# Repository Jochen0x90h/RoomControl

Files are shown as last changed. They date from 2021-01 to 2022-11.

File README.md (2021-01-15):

RoomControl
===========
Smart home room controller based on nRF52840 with MQTT and and IEEE 802.15.4 radio support. 
Buttons and relays for lights and blinds can also be connected with a local bus using 
LIN physical layer.

Control
-------
This is a 3D printed box with a display and digital potentiometer that gets installed in each
room instead of the floor heating thermostat. It can control the heating valve using an opto-triac,
connect to light and blind switches and relays using LIN physical layer and to battery-free switches
(EnOcan) using an IEEE 802.15.4 radio interface.

Switch
------
This is a wall switch and actor for lights and blinds that can be mounted behind Eltako E-Design
frames and rockers. It connects to the Control via a bus based on LIN physical layer.

Gateway
-------
This is a hat for rpi or compatible single board computers that connects to multiple Controls
via a IEEE 802.15.4 radio network and to an MQTT broker such as mosquitto.

License
-------
This work is licensed under a
[Creative Commons Attribution-NonCommercial-ShareAlike 4.0 International License][cc-by-nc-sa].

[][cc-by-nc-sa]

[cc-by-nc-sa]: http://creativecommons.org/licenses/by-nc-sa/4.0/
[cc-by-nc-sa-image]: https://licensebuttons.net/l/by-nc-sa/4.0/88x31.png

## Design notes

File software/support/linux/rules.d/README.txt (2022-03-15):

These files grant access to usb devices. Copy them into the rules.d directory:

sudo cp 49-nordic-dfu.rules /etc/udev/rules.d/
sudo cp 49-roomcontrol.rules /etc/udev/rules.d/

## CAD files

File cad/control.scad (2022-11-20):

// export checkist
// - resolution of circles high enough? ($fn = 128)
// - drill positions up to date? (gerber/drill2cad.py)
$fn = 128;

// variables

// pcb
pcbWidth = 70;
pcbHeight = 76;
pcbX = 0; // center of pcb
pcbY = 0;
pcbZ1 = 3;
pcbZ2 = pcbZ1+1.6; // mounting surface
pcbX1 = pcbX-pcbWidth/2;
pcbX2 = pcbX+pcbWidth/2;
pcbY1 = pcbY-pcbHeight/2;
pcbY2 = pcbY+pcbHeight/2;

// poti (Bourns PEC12R-4215F-S0024)
potiX = 22;
potiY = -22;
potiH1 = 7; // height of body above pcb (variant with switch)
potiH2 = 11.2; // height of shaft bearing above pcb
potiL = 17.5; // height of shaft end above pcb
potiF = 5; // shaft cutaway
potiZ1 = pcbZ2 + potiH1;
potiZ2 = pcbZ2 + potiH2;
potiZ4 = pcbZ2 + potiL;
potiZ3 = potiZ4 - potiF;
potiD1 = 7; // shaft bearing diameter
potiD2 = 6; // shaft diameter

// base
baseZ1 = 0;
baseZ2 = pcbZ1;

// cover
coverZ1 = pcbZ2;
coverZ2 = potiZ4 + 1; // use height of poti mounted on pcb plus cap
coverFit = 0.4;
coverOverlap = 2.5;

// wheel
wheelD1 = 10; // diameter of shaft
wheelD2 = 39; // diameter of wheel
wheelGap = 0.5; // visible air gab between box and wheel
wheelZ1 = potiZ3;
wheelZ2 = coverZ2 - 3; // thickness of wheel
wheelZ3 = coverZ2;

// pir lens
lensX = -23;
lensY = -30;
lensD1 = 8.9 + 0.1; // tolerance
lensD2 = 10.2 + 0.2; // tolerance
lensZ2 = coverZ2;
lensZ1 = lensZ2 - 4.35;
lensZ0 = lensZ1 - 4.5 - 0.1; // tolerance

// photo diode
photoX = lensX;
photoY = -14;
photoD = 5.1 + 0.1; // tolerance
photoZ2 = coverZ2;
photoZ1 = photoZ2 - 3.85;

// rectangular speaker
//speakerX = 0;
//speakerY = -25;
//speakerWidth = 25 + 0.2; // tolerance
//speakerHeight = 14 + 0.2; // tolerance
//speakerZ2 = wheelZ2 - 2;
//speakerZ1 = speakerZ2 - 4.5; // thickness of speaker

// round speaker
speakerX = 0;
speakerY = -25;
speakerDiameter = 28;
speakerZ2 = wheelZ2 - 2;
speakerZ1 = speakerZ2 - 5.2; // thickness of speaker


// micro usb connector
usbX = 22;
usbWidth = 8;
usbZ2 = pcbZ2 + 3; // thickness of usb connector
usbPlugWidth = 12;
usbPlugThickness = 8; // thickness of plug of usb cable

// ebyte e73 module
e73X = -13;
e73Width = 18.5;
e73Z2 = pcbZ2 + 2;

// display (2.42 inch)
displayTolerance = 0.4;
displayCableWidth1 = 13;
displayCableWidth2 = 16; // where the flat cable is connected to display
displayCableLength = 35;

// display screen (active area of display)
screenX = 0;
screenY = 20.5;
screenWidth = 57.01;
screenHeight = 29.49;
screenOffset = 1.08 + displayTolerance; // distance between upper panel border and upper screen border (tolerance at upper border)
screenX1 = screenX - screenWidth/2;
screenX2 = screenX + screenWidth/2;
screenY1 = screenY - screenHeight/2;
screenY2 = screenY + screenHeight/2;

// display panel
panelWidth = 60.5 + displayTolerance;
panelHeight = 37 + displayTolerance;
panelThickness1 = 1.2; // at side where cable is connected
panelThickness2 = 2.3;
panelX = screenX;
panelX1 = panelX - panelWidth / 2; // left border of panel
panelX2 = panelX + panelWidth / 2; // right border of panel
panelY2 = screenY + screenHeight/2+screenOffset; // upper border of panel
panelY1 = panelY2-panelHeight; // lower border of panel
panelY = (panelY2+panelY1)/2;
panelZ1 = coverZ2 - 1 - panelThickness2;
panelZ2 = coverZ2 - 1 - panelThickness1;
panelZ3 = coverZ2 - 1;
//echo(100+panelX1);
//echo(100-panelY1);
//echo(100+panelX2);
//echo(100-panelY2);

// power supply (34x20x15 https://www.hlktech.com/en/Goods-12.html)
powerX1 = 15.4;
powerX2 = 35.6;
powerY1 = 3.7;
powerY2 = 37.9;
powerZ2 = pcbZ2 + 15 + 0.2; // tolerance
assert(powerZ2 <= panelZ1, "power supply intersects display");

// cable clamps
clampsX1 = -16.3;
clampsX2 = 16.3;
clampsY1 = -10.5;
clampsY2 = 19;
clampsHeight = 13 + 1;


// cable hole
cableX1 = -17.0;
cableY1 = -1.6;
cableX2 = 34;
cableY2 = 10.2;
cableY = (cableY1 + cableY2) / 2;
fixationHeight = cableY2 - cableY1 - 2 * 2;


// box with center/size in x/y plane and z ranging from z1 to z2
module box(x, y, w, h, z1, z2) {
	translate([x-w/2, y-h/2, z1])
		cube([w, h, z2-z1]);
}

module cuboid(x1, y1, x2, y2, z1, z2) {
	translate([x1, y1, z1])
		cube([x2-x1, y2-y1, z2-z1]);
}

module barrel(x, y, d, z1, z2) {
	translate([x, y, z1])
		cylinder(r=d/2, h=z2-z1);
}

module cone(x, y, d1, d2, z1, z2) {
	translate([x, y, z1])
		cylinder(r1=d1/2, r2=d2/2, h=z2-z1);
}

module frustum(x, y, w1, h1, w2, h2, z1, z2) {
	// https://en.wikibooks.org/wiki/OpenSCAD_User_Manual/Primitive_Solids#polyhedron	
	points = [
		// lower square
		[x-w1/2,  y-h1/2, z1],  // 0
		[x+w1/2,  y-h1/2, z1],  // 1
		[x+w1/2,  y+h1/2, z1],  // 2
		[x-w1/2,  y+h1/2, z1],  // 3
		// upper square
		[x-w2/2,  y-h2/2, z2],  // 4
		[x+w2/2,  y-h2/2, z2],  // 5
		[x+w2/2,  y+h2/2, z2],  // 6
		[x-w2/2,  y+h2/2, z2]]; // 7
	faces = [
		[0,1,2,3],  // bottom
		[4,5,1,0],  // front
		[7,6,5,4],  // top
		[5,6,2,1],  // right
		[6,7,3,2],  // back
		[7,4,0,3]]; // left  
	polyhedron(points, faces);
}


// reference parts
// ---------------

module usb() {
	color([0.5, 0.5, 0.5])
	box(x=usbX, y=pcbY1+1, w=usbWidth, h=10, z1=pcbZ2-0.1, z2=usbZ2);		
}

module usbPlug() {
	usbPlugZ1 = (usbZ1+usbZ2)/2-usbPlugThickness/2;
	color([0, 0, 0])
	box(x=usbX, y=pcbY1-10, w=usbPlugWidth, h=14,
		z1=usbPlugZ1, z2=usbPlugZ1+usbPlugThickness);		
}

// ebyte e73 module
module e73() {
	color([0.0, 0.6, 0.0])
	box(x=e73X, y=pcbY1+1, w=e73Width, h=10, z1=pcbZ2-0.1, z2=e73Z2);			
}

// printed circuit board
module pcb() {
	color([0, 0.6, 0, 0.3])
	box(x=pcbX, y=pcbY, w=pcbWidth, h=pcbHeight,
		z1=pcbZ1, z2=pcbZ2);
}

// digital potentiometer
module poti() {
	x = potiX;
	y = potiY;
	color([0.5, 0.5, 0.5]) {
		box(x, y, 13.4, 12.4, pcbZ2, potiZ1);
		box(x, y, 15, 6, pcbZ2, potiZ1);
		barrel(x, y, potiD1, pcbZ2, potiZ2);
		difference() {
			barrel(x, y, potiD2, pcbZ2, potiZ4);
			box(x, y+potiD2/2, 10, 3, potiZ3, potiZ4+0.5);
		}
	}
}

//module relays() {
//	color([1, 1, 1]) {
//		cuboid(-23.2, 22.8, 37.5, 37.5, pcbZ2, pcbZ2+9.2);
//	}
//}

// transformer for power supply
module power() {
	color([0, 0, 0]) {
		cuboid(powerX1, powerY1, powerX2, powerY2, pcbZ2-0.1, powerZ2);
	}	
}

// cable clamps
module clamps() {
	color([0.8, 0.8, 0.8]) {
		cuboid(clampsX1, clampsY1, clampsX2, clampsY2,
			pcbZ1 - clampsHeight, pcbZ1);
	}		
}


// 

module wheel() {
	x = potiX;
	y = potiY;

	// wheel
	difference() {
		// wheel
		barrel(x, y, wheelD2, wheelZ2, wheelZ3);

		// cutout for poti shaft (with tolerance)
		box(x=x, y=y, w=10, h=4.5, z1=1, z2=potiZ4+0.1);
		box(x=x, y=y, w=4.5, h=10, z1=1, z2=potiZ4+0.1);
	}
	
	// shaft holder for poti shaft
	difference() {
		intersection() {
			// box that has 1mm wall on sides
			box(x=x, y=y, w=8, h=8, z1=wheelZ1, z2=wheelZ2+1);

			// make round corners
			barrel(x, y, wheelD1, wheelZ1, wheelZ2+1);
		}

		// subtract rounded hole
		intersection() {
			box(x=x, y=y, w=potiD2, h=potiD2, z1=wheelZ1-1, z2=wheelZ3-1);
			barrel(x, y, 3.8*2, wheelZ1-1, wheelZ3-1);
		}
	}
	
	// poti shaft cutaway
	difference() {
		// fill shaft cutaway which is 1.5mm
		union() {
			box(x=x, y=y+2.5, w=1, h=2, z1=potiZ3, z2=wheelZ3-2);
			box(x=x, y=y+2.0, w=2, h=1, z1=potiZ3, z2=wheelZ3-2);
		}

		// subtract slanted corners to ease insertion of poti shaft
		translate([x, y+1.6, potiZ3-0.5])
			rotate([30, 0, 0])
				box(x=0, y=0, w=4, h=1, z1=0, z2=2);
	}
}

// for adding wheel base
module wheelBase(x, y) {
	// base in z-direction: 1mm air, 2mm wall
	barrel(x, y, wheelD2+(wheelGap+2)*2, wheelZ2-1-2, wheelZ3);
	
	// shaft radial: 5mm wheel shaft, air gap, 1mm wall
	// zhaft z-direction: 2mm wall, 1mm air, wheel
	barrel(x, y, wheelD1+(wheelGap+1)*2, wheelZ1-2-1, wheelZ3);

	// shaft radial: poti shaft, no air gap, 1.5mm wall
	barrel(x, y, potiD1+1.5*2, potiZ1, wheelZ3);
}

// for subtracting from wheel base
module potiCutout(x, y) {
	// cutout for wheel: 3mm wheel, 1mm air
	barrel(x, y, wheelD2+wheelGap*2, wheelZ2-1, coverZ2+1);

	// hole for poti shaft bearing
	barrel(x, y, potiD1+0.1*2, pcbZ2, wheelZ2);

	// hole for poti shaft
	barrel(x, y, potiD2+0.1*2, pcbZ2, wheelZ2);

	// hole for wheel shaft
	barrel(x, y, wheelD1+wheelGap*2, wheelZ1-1, wheelZ2);
}

// snap lock between cover and base
module snap(x, l) {
	translate([x, 0, coverZ1+1])
		rotate([0, 45, 0])
			cuboid(x1=-0.65, x2=0.65, y1=-l/2, y2=l/2, z1=-0.65, z2=0.65);
}

module drill(x, y, d) {
	h1 = d + 1;
	w1 = h1;
	h2 = d + 0.2;
	w2 = h2;
	frustum(x, y, w2, h2, w1, h1, pcbZ1-1.5, pcbZ1+0.1);
	box(x, y, w2, h2, pcbZ2-4, pcbZ1);	
}
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

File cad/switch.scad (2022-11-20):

$fn = 128;

// production constraints
minWall = 1;
minGap = 0.8;

// pcb
pcbZ1 = 0;
pcbZ2 = 1.6;
pinZ = pcbZ1 + 4; // pins soldered into through-hole pads

// dimensions
Z = 12; // overall height in Z-direction
rockerZ = 16; // height of rocker surface

// actuation angle
angle = 5.4; // maximum actuation angle
tanAngle = tan(angle);


// axis
axisD = 2.5;
axisX2 = /*37.2*/36.8 / 2; // outer rocker axis
axisX1 = 37.2/2 - 15.85; // inner rocker axis
axisZ = Z - 1.3;
axisCoutoutWidth = 7;
axisCutoutZ = axisZ - 2.5;

// body
bodyWidth = 40;

// switch actuator
actuatorWidth = 3.2;
actuatorX = 17 / 2;
actuatorY = 20 / 2;
actuatorZ = axisZ - 1.3 + 2;


// micro switch Omron D2F-01
switchWidth = 5.8 + 0.2; // tolerance
switchHeight = 12.8;
switchX = switchHeight / 2;
switchY = actuatorY;
switchZ2 = pcbZ2+6.5;//actuatorZ - 1 - 1;
switchZ1 = switchZ2 - 5;
switchZ0 = switchZ1 - 1.5;
switchZ3 = switchZ2 + 1; // actuator
switchesX2 = switchX + switchHeight / 2;
switchesWidth = switchesX2 * 2;
switchesY2 = switchY + switchWidth / 2;


// mount
mountWidth = 48;
mountHeight = 48;
mountRight = mountWidth / 2;
mountTop = mountHeight / 2;

// mount part 1 (sides)
mount1Width = 4;
mount1Height = 18.2;
mount1X = mountRight - mount1Width / 2;
mount1Y = mount1Height / 2;

// mount part 2 (corners, rotated by 45°)
mount2Width = 9.5;
mount2Height = 2.25;
mount2Y2 = 58.1 / 2;
mount2Y = mount2Y2 - mount2Height / 2;

// mount part 3 (top/bottom)
mount3Width = 18.2 * 2;
mount3Height = 3;//mountTop - barY2 - minGap;
mount3Y = mountTop - mount3Height / 2;

// mount part 4 (spring support)
mount4Width = 5;
mount4Height = mountTop - switchesY2;
mount4Y = (mountTop + switchesY2) / 2;

// mount Z
mountZ1 = pcbZ2;
mountZ2 = mountZ1 + 2; // thickness of frame (Eltako E-Design)


// clamp part 1 (sides)
clamp1Width = 1.5;
clamp1Height = mount1Height;
clamp1X = mountRight - clamp1Width / 2;
clamp1Y = mount1Y;

// clamp part 2 (corners and frame clamps, rotated by 45°)
clamp2Width1 = mount2Width;
clamp2Width2 = 6.5;
clamp2Height = 1.5;
clamp2Y = mount2Y2 - clamp2Height / 2;

// clamp Z
clampZ1 = mountZ2 + minGap;
clampZ2 = Z - mountTop * tanAngle; // fits under rockers at top/bottom edge
clampZ3 = Z - mount1Height * tanAngle;


// middle carrier
carrierWidth = mountWidth;
carrierHeight = (switchY - switchWidth / 2) * 2;
carrierZ1 = pcbZ2;
carrierZ2 = pinZ + 1;

// top above switches
topWidth = switchesWidth;
topHeight = switchWidth + 2;
topY = switchY;
topY1 = switchY - topHeight/2;
topY2 = switchY + topHeight/2;

// screws
screwX = 20.5;
screwY = -4;
screwD = 2.5;
screwMountSize = 6; // diameter of screw mount

// actuator bar (front)
barWidth = (32 + 2) / 2;
barX = barWidth / 2;
barY1 = 34.4 / 2;
barY2 = 40 / 2;
barY = (barY1 + barY2) / 2;
barZ2 = axisZ - 1.3;
barZ1 = barZ2 - 1.5; // thickness of bar
//echo(barZ1);
barHeight = barY2 - barY1;
barTravel = barY2 * tanAngle;
//echo(barTravel);

// spring below actuator bar
springZ = (pcbZ2 + barZ1) / 2; // "middle" of spring
springZ1 = springZ - barTravel / 2; // lower block
springZ2 = springZ + barTravel / 2; // upper block


// led (Kingbright WP710A10LZGCK)
//ledX = 15.75;
//ledY = 23;//22;
ledX = 15.5;
ledY = 0;
ledD1 = 2.9;
ledD2 = 3.2;
ledZ2 = rockerZ - 2.5 - ledY * tanAngle - 0.1; // tolerance
ledZ1 = ledZ2 - 3.6; 
ledZ0 = ledZ2 - 5.4;


// lever arm
leverX1 = switchesX2 + 1; // 1mm left/right tolerance
leverX2 = axisX2 - minWall - minGap;
leverX = (leverX1 + leverX2) / 2;
leverY1 = ledD2 / 2;
leverY2 = topY2 + minGap;
leverY = (leverY1 + leverY2) / 2;
leverWidth = leverX2 - leverX1;
leverHeight = leverY2 - leverY1;

// lever front
front1Y1 = topY2 + minGap;
front1Y2 = barY1 - minGap;
front1Y = (front1Y1 + front1Y2) / 2;
front1Height = front1Y2 - front1Y1;
front2Y1 = topY2 + minGap;
front2Y2 = 33.3 / 2;
front2Y = (front2Y1 + front2Y2) / 2;
front2Height = front2Y2 - front2Y1;

// lever Z
leverZ1 = pinZ + front1Y1 * tanAngle;
leverZ2 = Z - 4;



// box with center/size in x/y plane and z ranging from z1 to z2
module box(x, y, w, h, z1, z2) {
	translate([x-w/2, y-h/2, z1])
		cube([w, h, z2-z1]);
}

module cuboid(x1, y1, x2, y2, z1, z2) {
	translate([x1, y1, z1])
		cube([x2-x1, y2-y1, z2-z1]);
}

module barrel(x, y, d, z1, z2) {
	translate([x, y, z1])
		cylinder(r=d/2, h=z2-z1);
}

module axis(x, y, d, l, z) {
	translate([x-l/2, y, z])
		rotate([0, 90, 0])
			cylinder(r=d/2, h=l);
}

module frustum(x, y, w1, h1, w2, h2, z1, z2) {
	// https://en.wikibooks.org/wiki/OpenSCAD_User_Manual/Primitive_Solids#polyhedron	
	points = [
		// lower square
		[x-w1/2,  y-h1/2, z1],  // 0
		[x+w1/2,  y-h1/2, z1],  // 1
		[x+w1/2,  y+h1/2, z1],  // 2
		[x-w1/2,  y+h1/2, z1],  // 3
		// upper square
		[x-w2/2,  y-h2/2, z2],  // 4
		[x+w2/2,  y-h2/2, z2],  // 5
		[x+w2/2,  y+h2/2, z2],  // 6
		[x-w2/2,  y+h2/2, z2]]; // 7
	faces = [
		[0,1,2,3],  // bottom
		[4,5,1,0],  // front
		[7,6,5,4],  // top
		[5,6,2,1],  // right
		[6,7,3,2],  // back
		[7,4,0,3]]; // left  
	polyhedron(points, faces);
}

module slopeX(x, y, w, h, z1, z2, z3, z4, rl=1) {
	// https://en.wikibooks.org/wiki/OpenSCAD_User_Manual/Primitive_Solids#polyhedron

	if (rl < 0) {
		slopeX(x, y, w, h, z2, z1, z4, z3);
	} else {
		x1 = x - w / 2;
		x2 = x + w / 2;
		y1 = y - h / 2;
		y2 = y + h / 2;
		
		points = [
			// lower square
			[x1,  y1, z1],  // 0
			[x2,  y1, z2],  // 1
			[x2,  y2, z2],  // 2
			[x1,  y2, z1],  // 3
			// upper square
			[x1,  y1, z3],  // 4
			[x2,  y1, z4],  // 5
			[x2,  y2, z4],  // 6
			[x1,  y2, z3]]; // 7
		faces = [
			[0,1,2,3],  // bottom
			[4,5,1,0],  // front
			[7,6,5,4],  // top
			[5,6,2,1],  // right
			[6,7,3,2],  // back
			[7,4,0,3]]; // left  
		polyhedron(points, faces);
	}
}

module slopeY(x, y, w, h, z1, z2, z3, z4, tb=1) {
	// https://en.wikibooks.org/wiki/OpenSCAD_User_Manual/Primitive_Solids#polyhedron

	if (tb < 0) {
		slopeY(x, y, w, h, z2, z1, z4, z3);
	} else {
		x1 = x - w / 2;
		x2 = x + w / 2;
		y1 = y - h / 2;
		y2 = y + h / 2;	
		
		points = [
			// lower square
			[x1,  y1, z1],  // 0
			[x2,  y1, z1],  // 1
			[x2,  y2, z2],  // 2
			[x1,  y2, z2],  // 3
			// upper square
			[x1,  y1, z3],  // 4
			[x2,  y1, z3],  // 5
			[x2,  y2, z4],  // 6
			[x1,  y2, z4]]; // 7
		faces = [
			[0,1,2,3],  // bottom
			[4,5,1,0],  // front
			[7,6,5,4],  // top
			[5,6,2,1],  // right
			[6,7,3,2],  // back
			[7,4,0,3]]; // left  
		polyhedron(points, faces);
	}
}

module drill(x, y, d) {
	shift = 0;
	h1 = 2;
	w1 = h1 + shift;
	h2 = d + 0.1;
	w2 = h2 + shift;
	frustum(x, y, w1, h1, w2, h2, pcbZ2-0.1, pcbZ2+1.5);
	box(x, y, w2, h2, pcbZ2, pinZ);
}

module drills() {
	drill(-19.3, 25.5, 0.8);
	drill(-17.3, 25.5, 0.8);
	drill(-15.3, 25.5, 0.8);
	drill(-13.3, 25.5, 0.8);
	drill(-11.3, 25.5, 0.8);
	drill(-15.5, 10, 0.9);
	drill(-13.7, 10, 0.9);
	drill(13.7, 10, 0.9);
	drill(15.5, 10, 0.9);
	drill(-22.54, 10, 1);
	drill(-22.54, 4.92, 1);
	drill(-22.54, 2.38, 1);
	drill(-22.54, -0.16, 1);
	drill(-17.46, 10, 1);
	drill(-17.46, 4.92, 1);
	drill(-17.46, 2.38, 1);
	drill(-17.46, -0.16, 1);
	drill(-11.76, 2.54, 1);
	drill(-11.76, -2.54, 1);
	drill(-9.22, 2.54, 1);
	drill(-9.22, -2.54, 1);
	drill(-6.68, 2.54, 1);
	drill(-6.68, -2.54, 1);
	drill(-1.6, 2.54, 1);
	drill(-1.6, -2.54, 1);
	drill(1.6, 2.54, 1);
	drill(1.6, -2.54, 1);
	drill(6.68, 2.54, 1);
	drill(6.68, -2.54, 1);
	drill(9.22, 2.54, 1);
	drill(9.22, -2.54, 1);
	drill(11.76, 2.54, 1);
	drill(11.76, -2.54, 1);
	drill(17.46, 10, 1);
	drill(17.46, 4.92, 1);
	drill(17.46, 2.38, 1);
	drill(17.46, -0.16, 1);
	drill(22.54, 10, 1);
	drill(22.54, 4.92, 1);
	drill(22.54, 2.38, 1);
	drill(22.54, -0.16, 1);
	drill(-12.5, -16, 1.1);
	drill(-12.5, -21, 1.1);
	drill(-11.48, 10, 1.1);
	drill(-11.48, -10, 1.1);
	drill(-7.5, 21, 1.1);
	drill(-7.5, 16, 1.1);
	drill(-7.5, -16, 1.1);
	drill(-7.5, -21, 1.1);
	drill(-6.4, 10, 1.1);
	drill(-6.4, -10, 1.1);
	drill(-2.5, 21, 1.1);
	drill(-2.5, 16, 1.1);
	drill(-2.5, -16, 1.1);
	drill(-2.5, -21, 1.1);
	drill(-1.32, 10, 1.1);
	drill(-1.32, -10, 1.1);
	drill(1.32, 10, 1.1);
	drill(1.32, -10, 1.1);
	drill(2.5, 21, 1.1);
	drill(2.5, 16, 1.1);
	drill(2.5, -16, 1.1);
	drill(2.5, -21, 1.1);
	drill(6.4, 10, 1.1);
	drill(6.4, -10, 1.1);
	drill(7.5, 21, 1.1);
	drill(7.5, 16, 1.1);
	drill(7.5, -16, 1.1);
	drill(7.5, -21, 1.1);
	drill(11.48, 10, 1.1);
	drill(11.48, -10, 1.1);
	drill(12.5, -16, 1.1);
	drill(12.5, -21, 1.1);
}

module switchPins(x, y, angle) {
	translate([x, y, 0]) {
		rotate([0, 0, angle]) {
					
			// holes
			axis(0, 6.5/2, 1.9, 1*2, switchZ1);
			axis(0, -6.5/2, 1.9, 1*2, switchZ1);
		}
	}
}

module catwalk(x, w) {
	for (tb = [1, -1]) {
		slopeY(x, carrierHeight/4*tb,
			w, carrierHeight/2,
			pcbZ2, pcbZ2,
			Z, Z-carrierHeight/2*tanAngle,
			tb);
	}
}
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

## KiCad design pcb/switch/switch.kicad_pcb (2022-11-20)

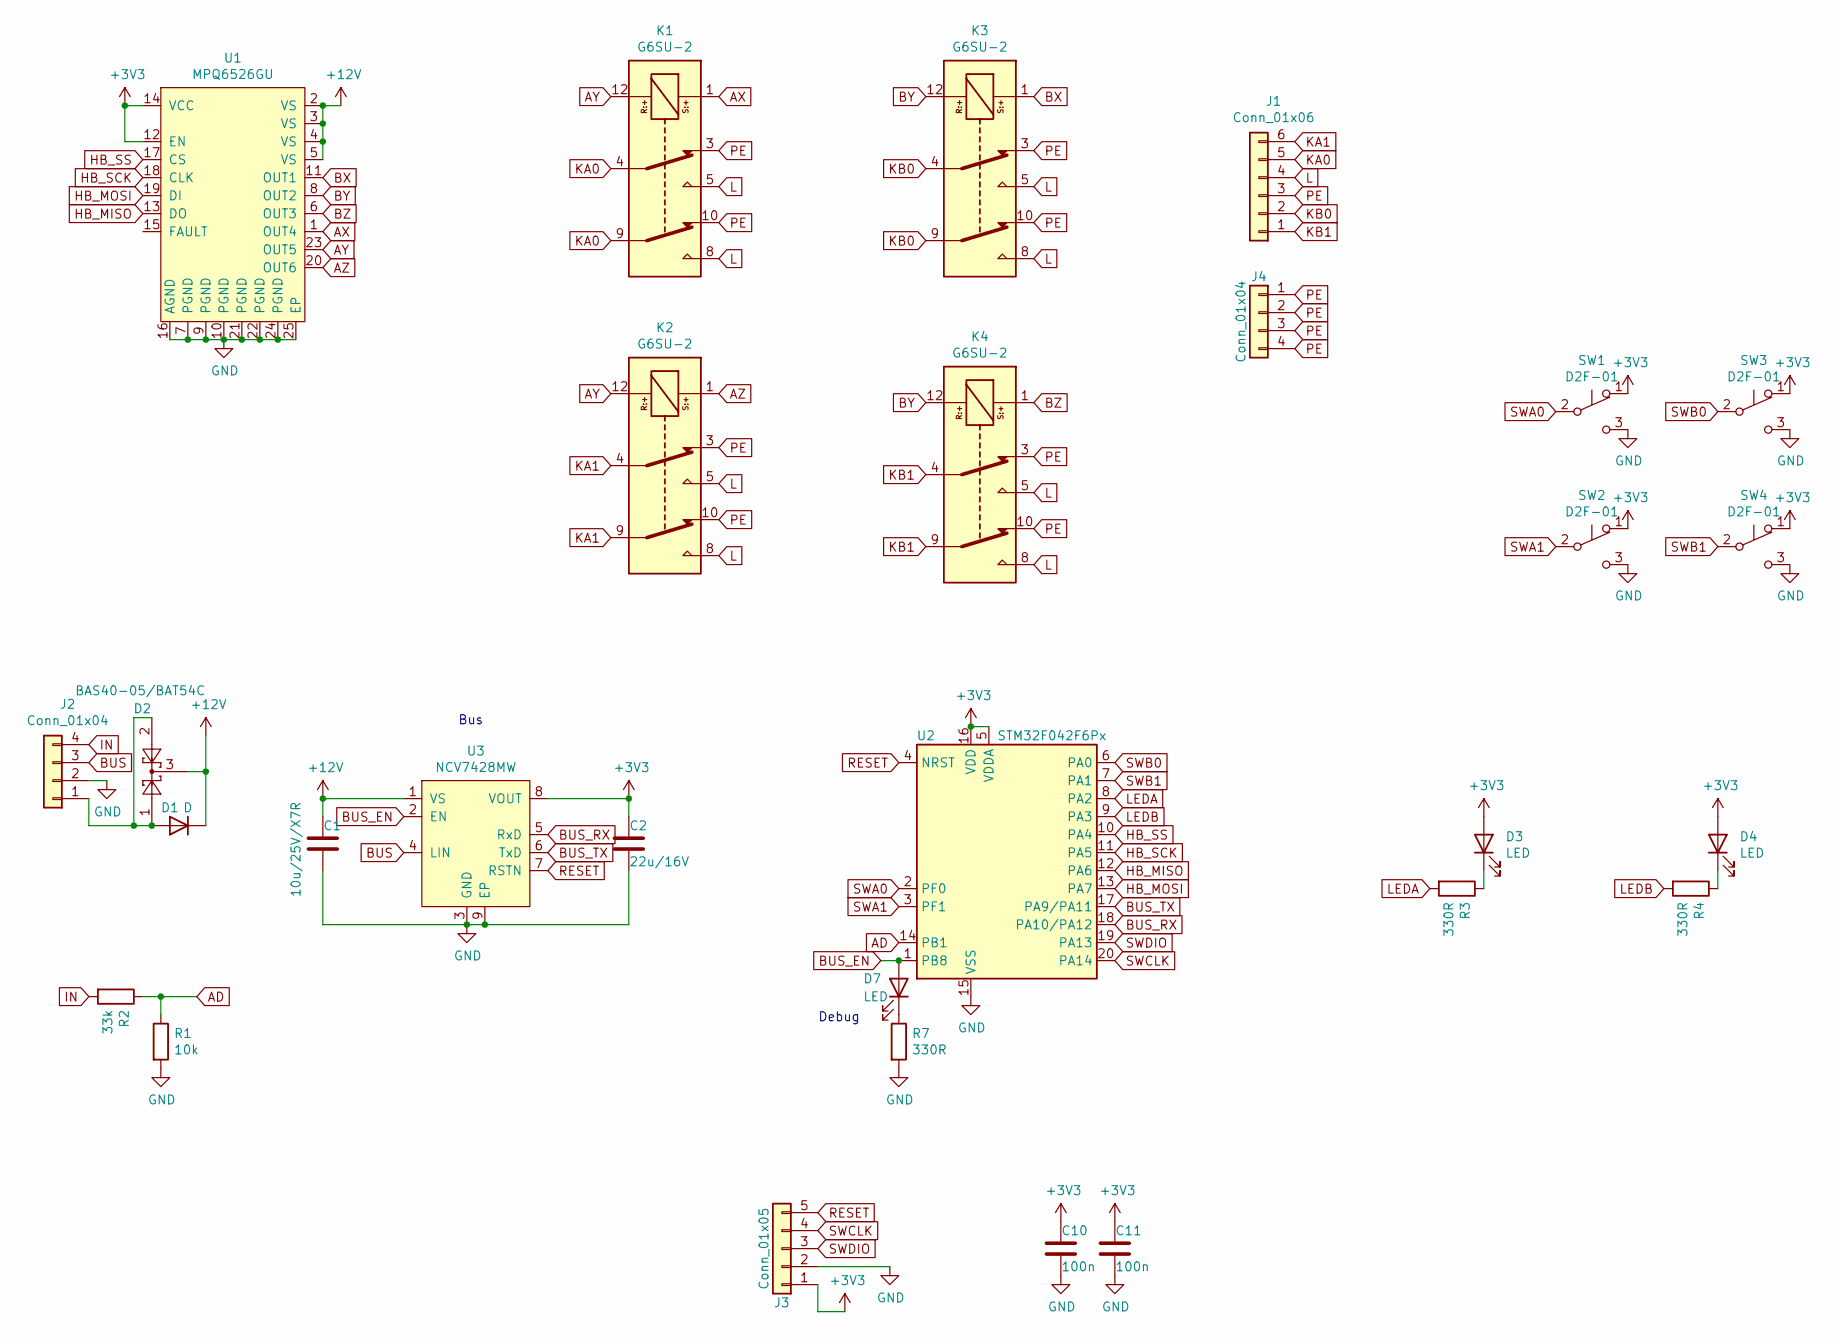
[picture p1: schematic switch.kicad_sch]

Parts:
C1: 10u/25V/X7R; C_1206_3216Metric
C2: 22u/16V; C_0805_2012Metric
C10, C11: 100n; C_0603_1608Metric
D1: D; D_1206_3216Metric_Castellated
D2: BAS40-05/BAT54C; SOT-23
D3, D4: LED; DiodeHolesSwitch
D7: LED; LED_0805_2012Metric_Castellated
J1: Conn_01x06; Wago_236-406
J2: Conn_01x04; Wago_236-404
J3: Conn_01x05; PinHeader_1x05_P2.00mm_Vertical
J4: Conn_01x04; Switch_Mount
K1, K2, K3, K4: G6SU-2
R1: 10k; R_0603_1608Metric
R2: 33k; R_1206_3216Metric
R3, R4, R7: 330R; R_0603_1608Metric
SW1, SW2, SW3, SW4: D2F-01
U1: MPQ6526GU
U2: STM32F042F6Px; STM32F042F6
U3: NCV7428MW

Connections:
+3V3: C2.1, C10.1, C11.1, D3.2 (A), D4.2 (A), J3.1, SW1.1 (A), SW2.1 (A), SW3.1 (A), SW4.1 (A), U1.12 (EN), U1.14 (VCC), U2.5 (VDDA), U2.16 (VDD), U3.8 (VOUT)
+12V: C1.1, D1.1 (K), D2.3, U1.2 (VS), U1.3 (VS), U1.4 (VS), U1.5 (VS), U3.1 (VS)
AD: R1.1, R2.1, U2.14 (PB1)
AX: K1.1, U1.1 (OUT4)
AY: K1.12, K2.12, U1.23 (OUT5)
AZ: K2.1, U1.20 (OUT6)
BUS: J2.3, U3.4 (LIN)
BUS_EN: D7.2 (A), U2.1 (PB8), U3.2 (EN)
BUS_RX: U2.18 (PA10/PA12), U3.5 (RxD)
BUS_TX: U2.17 (PA9/PA11), U3.6 (TxD)
BX: K3.1, U1.11 (OUT1)
BY: K3.12, K4.12, U1.8 (OUT2)
BZ: K4.1, U1.6 (OUT3)
GND: C1.2, C2.2, C10.2, C11.2, J2.2, J3.2, R1.2, R7.2, SW1.3 (C), SW2.3 (C), SW3.3 (C), SW4.3 (C), U1.7 (PGND), U1.9 (PGND), U1.10 (PGND), U1.16 (AGND), U1.21 (PGND), U1.22 (PGND), U1.24 (PGND), U1.25 (EP), U2.15 (VSS), U3.3 (GND), U3.9 (EP)
HB_MISO: U1.13 (DO), U2.12 (PA6)
HB_MOSI: U1.19 (DI), U2.13 (PA7)
HB_SCK: U1.18 (CLK), U2.11 (PA5)
HB_SS: U1.17 (CS), U2.10 (PA4)
IN: J2.4, R2.2
KA0: J1.5, K1.4, K1.9
KA1: J1.6, K2.4, K2.9
KB0: J1.2, K3.4, K3.9
KB1: J1.1, K4.4, K4.9
L: J1.4, K1.5, K1.8, K2.5, K2.8, K3.5, K3.8, K4.5, K4.8
LEDA: R3.2, U2.8 (PA2)
LEDB: R4.2, U2.9 (PA3)
unnamed: D1.2 (A), D2.1, D2.2, J2.1
unnamed: D3.1 (K), R3.1
unnamed: D4.1 (K), R4.1
unnamed: D7.1 (K), R7.1
PE: J1.3, J4.1, J4.2, J4.3, J4.4, K1.3, K1.10, K2.3, K2.10, K3.3, K3.10, K4.3, K4.10
RESET: J3.5, U2.4 (NRST), U3.7 (RSTN)
SWA0: SW1.2 (B), U2.2 (PF0)
SWA1: SW2.2 (B), U2.3 (PF1)
SWB0: SW3.2 (B), U2.6 (PA0)
SWB1: SW4.2 (B), U2.7 (PA1)
SWCLK: J3.4, U2.20 (PA14)
SWDIO: J3.3, U2.19 (PA13)

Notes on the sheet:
Debug
Bus

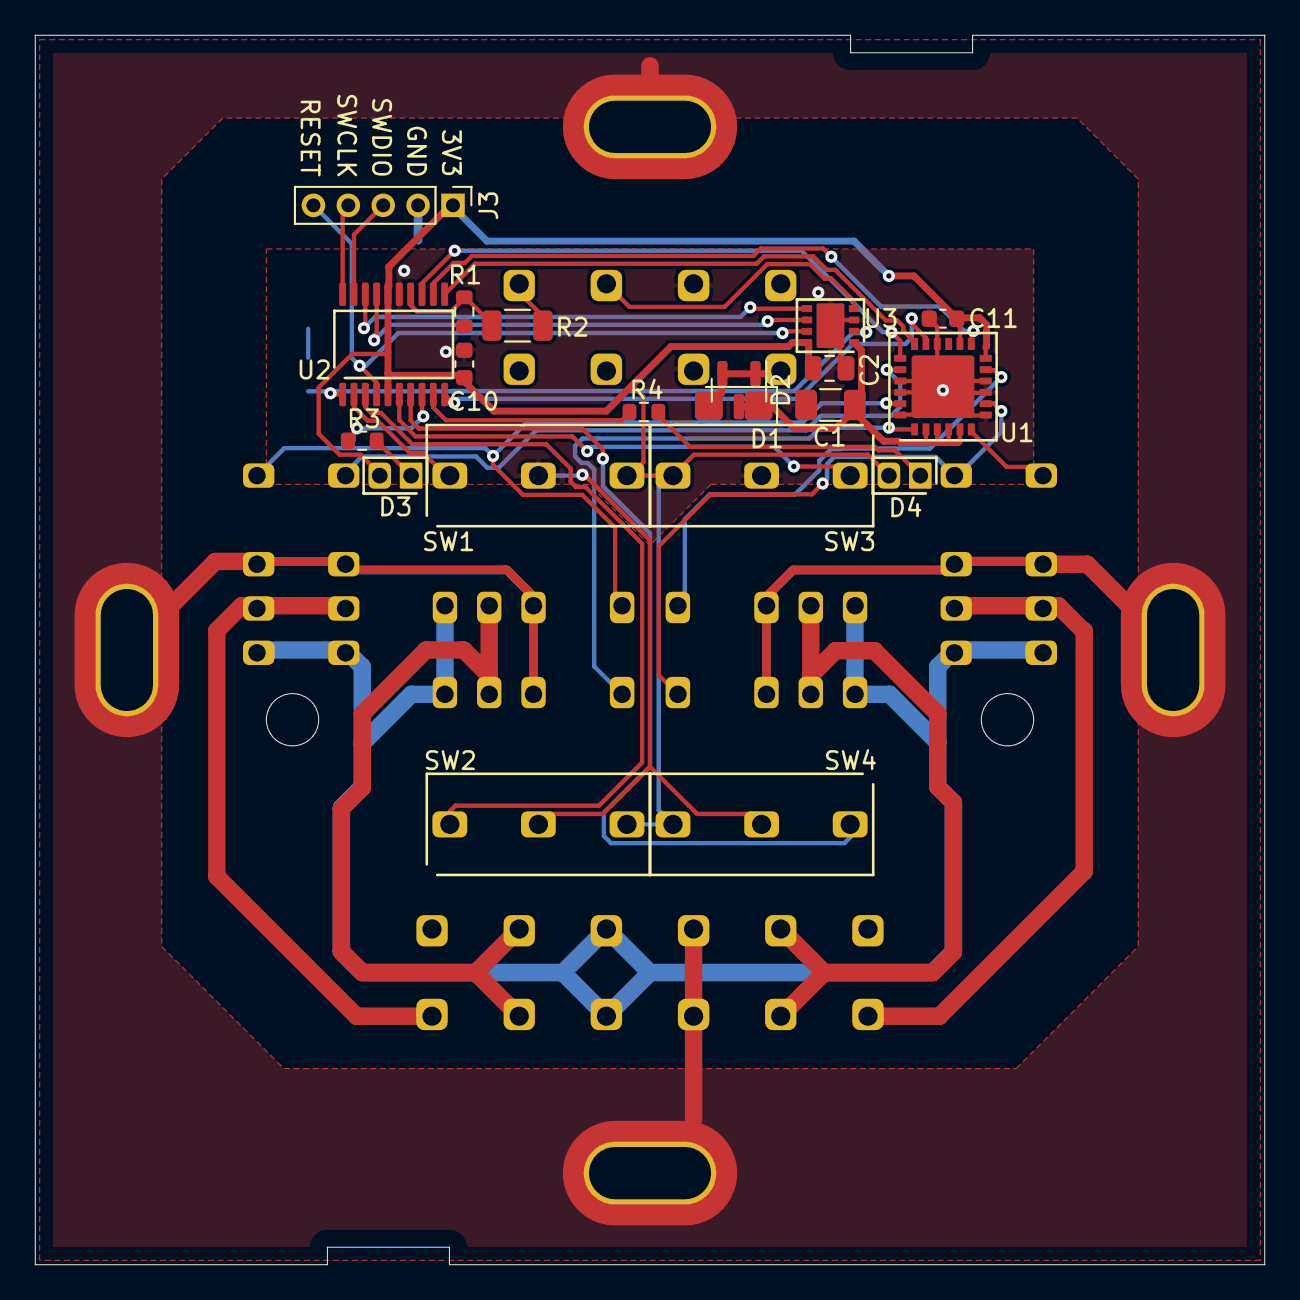
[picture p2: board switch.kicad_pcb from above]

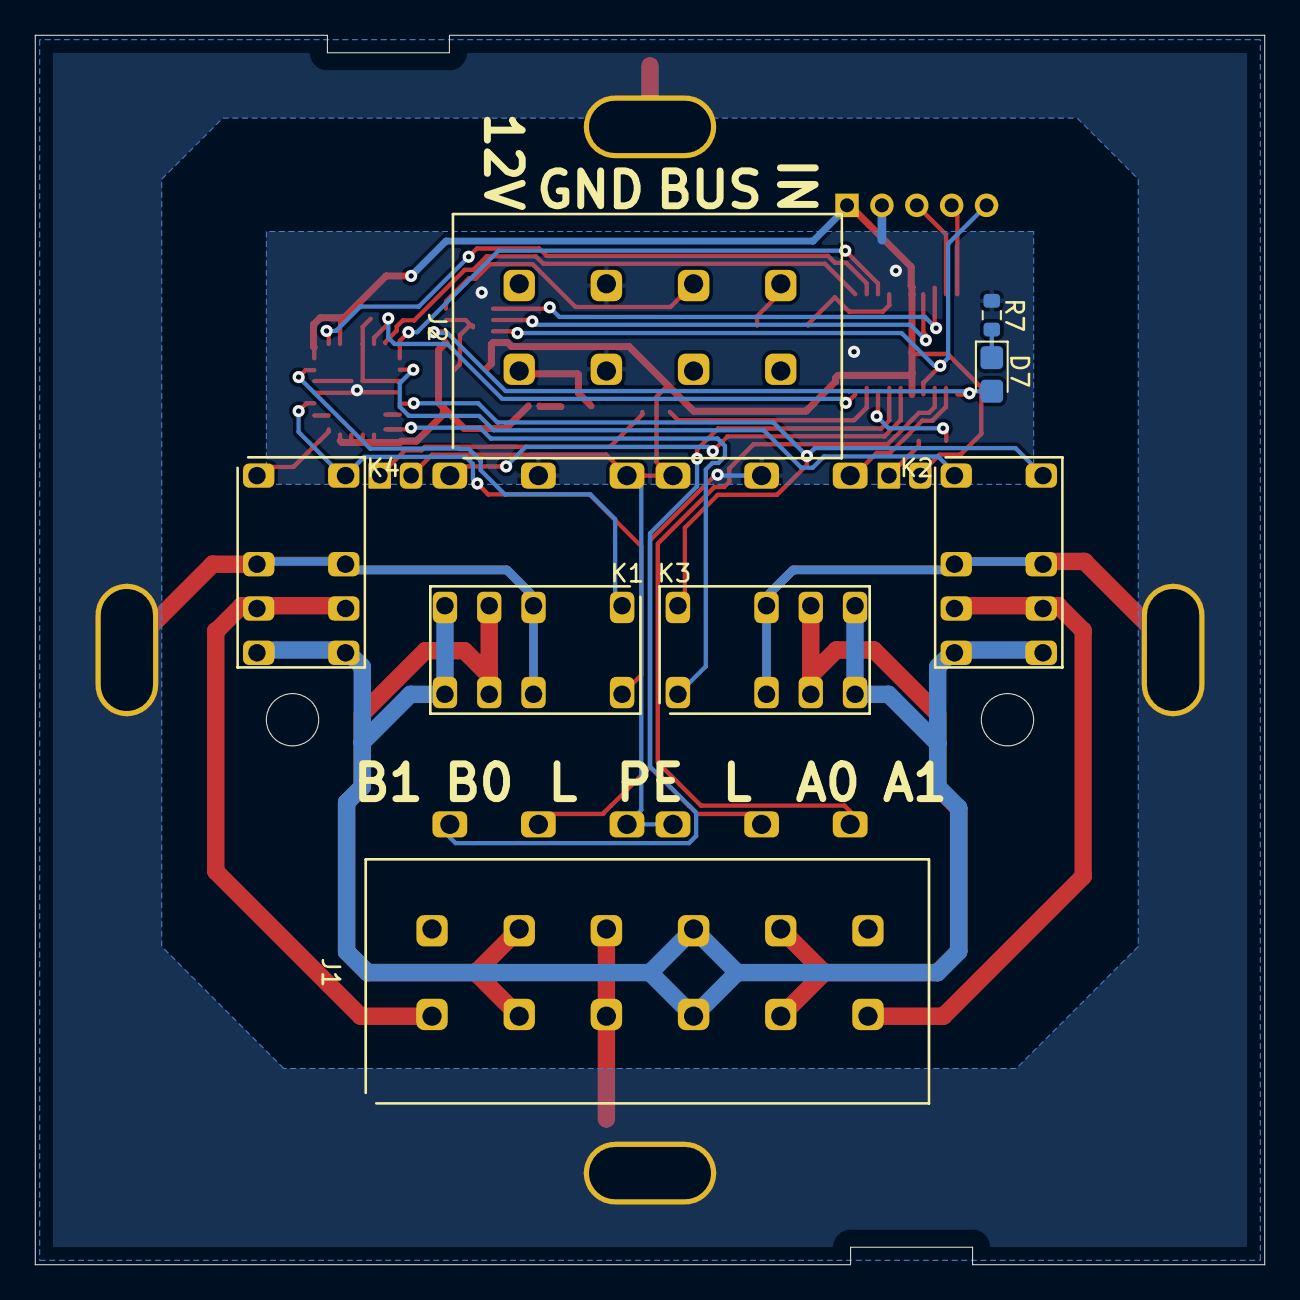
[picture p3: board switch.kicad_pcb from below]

Board: 2 copper layers, 70.5 x 70.5 mm, 29 parts (8 on the bottom side), 38 nets.

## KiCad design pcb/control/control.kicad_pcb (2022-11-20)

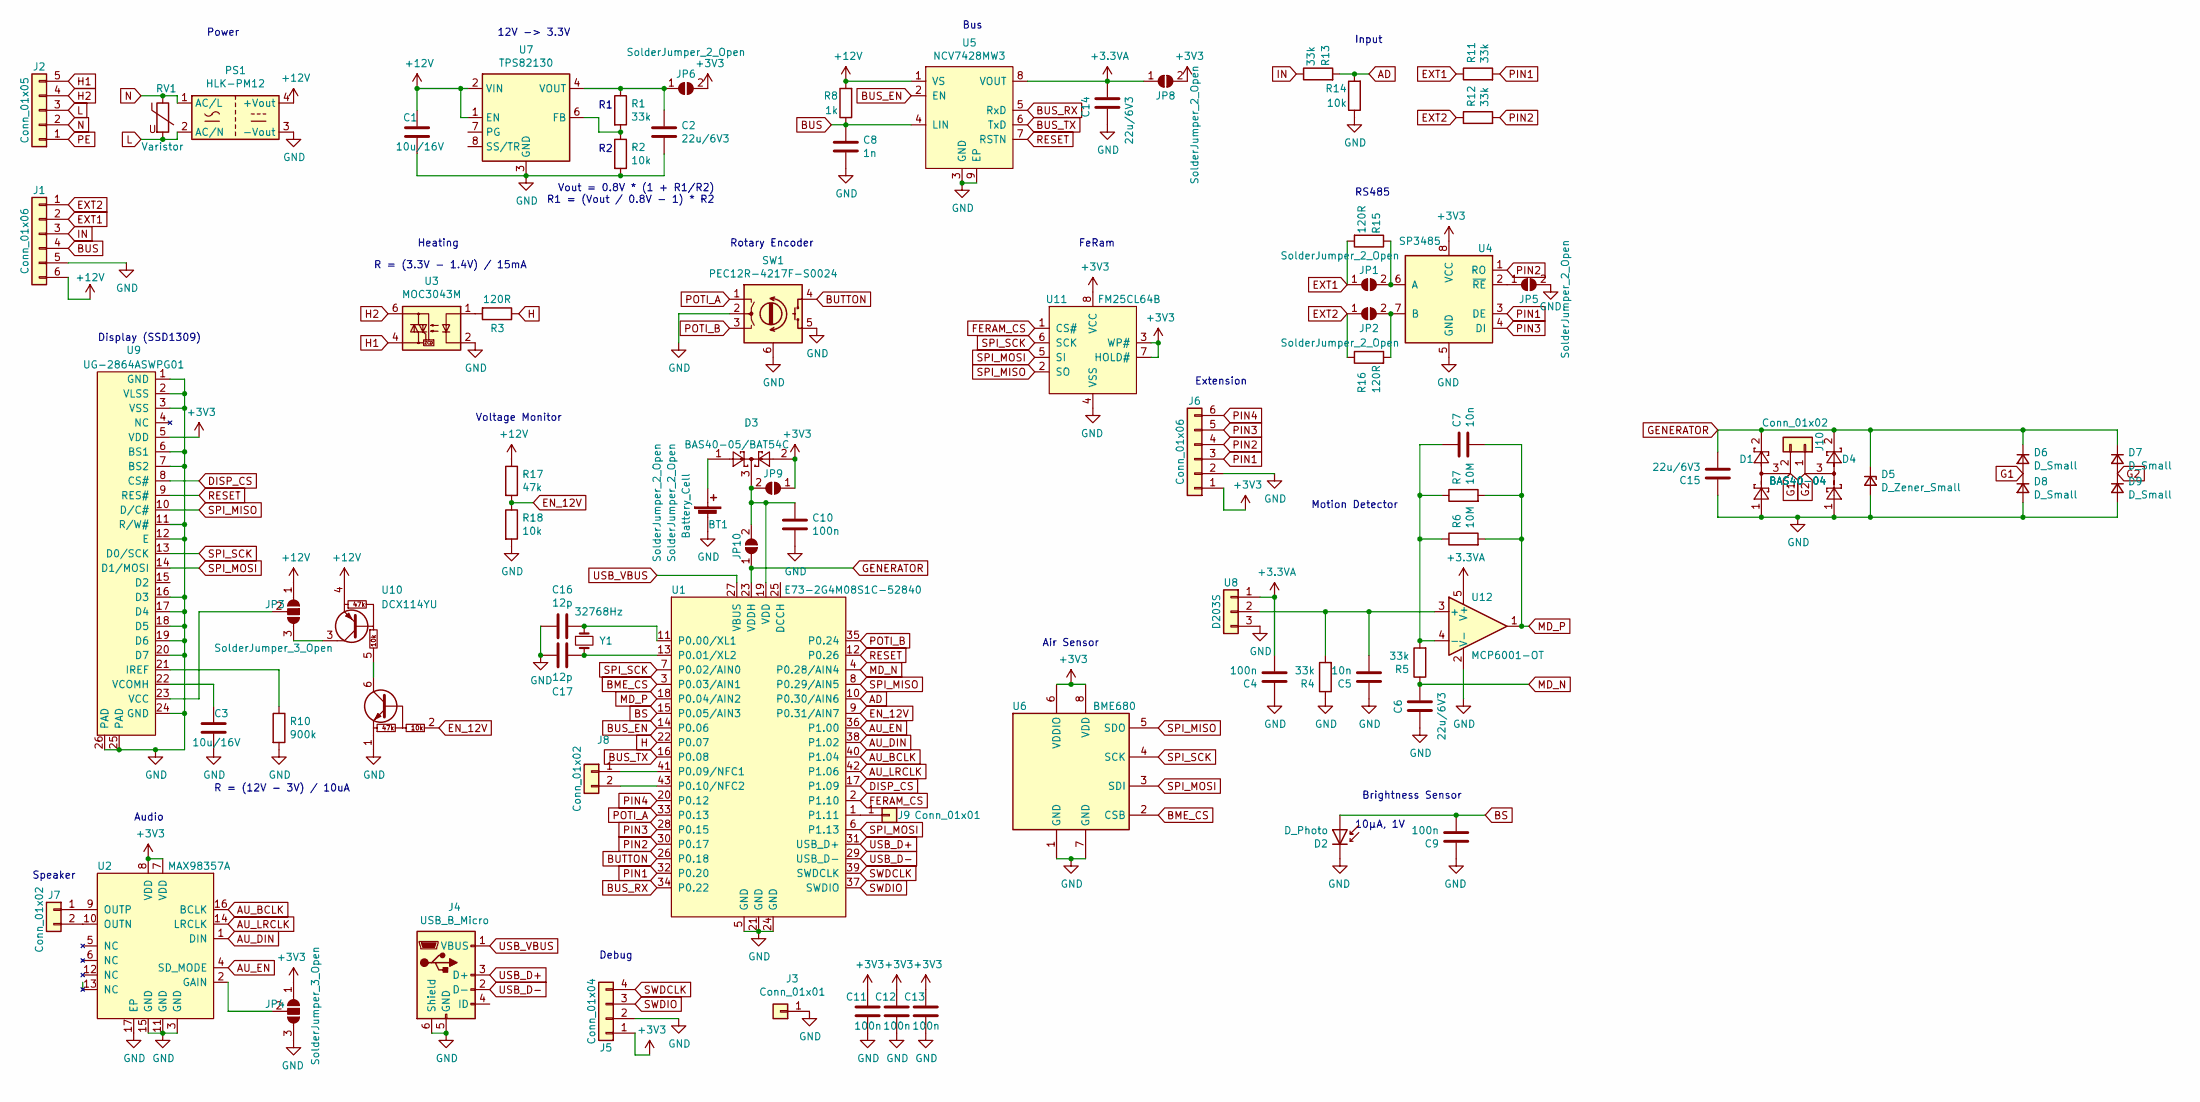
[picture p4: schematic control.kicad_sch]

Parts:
BT1: Battery_Cell; Battery_2032
C1, C3: 10u/16V; C_1206_3216Metric
C2, C6, C14, C15: 22u/6V3; C_0805_2012Metric
C4, C9, C10, C11, C12, C13: 100n; C_0603_1608Metric
C5, C7: 10n; C_0603_1608Metric
C8: 1n; C_0603_1608Metric
C16, C17: 12p; C_0603_1608Metric
D1, D4: BAS40-04; SOT-23
D2: D_Photo; DiodeHoles
D3: BAS40-05/BAT54C; SOT-23
D5: D_Zener_Small; D_SOD-323F
D6, D7, D8, D9: D_Small; D_1206_3216Metric_Castellated
J1: Conn_01x06; Wago_236-406
J2: Conn_01x05; Wago_236-405
J3: Conn_01x01; PinHeader_1x01_P2.54mm_Vertical
J4: USB_B_Micro; USB_Micro-B
J5: Conn_01x04; PinHeader_1x04_P2.00mm_Vertical
J6: Conn_01x06; PinHeader_1x06_P2.54mm_Vertical
J7, J10: Conn_01x02; PinHeader_1x02_P2.54mm_Vertical
J8: Conn_01x02; PinHeader_1x02_P2.00mm_Vertical
J9: Conn_01x01; TestPoint_Pad_1.5x1.5mm
JP1, JP2, JP5, JP6, JP8, JP9, JP10: SolderJumper_2_Open; Jumper2
JP3, JP4: SolderJumper_3_Open; Jumper3
PS1: HLK-PM12; HLK-PMxx
R1, R4, R5: 33k; R_0603_1608Metric
R2, R14, R18: 10k; R_0603_1608Metric
R3, R15, R16: 120R; R_1206_3216Metric
R6, R7: 10M; R_0603_1608Metric
R8: 1k; R_1206_3216Metric
R10: 900k; R_0603_1608Metric
R11, R12, R13: 33k; R_1206_3216Metric
R17: 47k; R_0603_1608Metric
RV1: Varistor; S10K275
SW1: PEC12R-4217F-S0024; PEC12R
U1: E73-2G4M08S1C-52840
U2: MAX98357A
U3: MOC3043M
U4: SP3485; SOIC-8_3.9x4.9mm_P1.27mm
U5: NCV7428MW3; NCV7428MW
U6: BME680
U7: TPS82130
U8: D203S
U9: UG-2864ASWPG01; Connector-Flat-24_P0.5mm
U10: DCX114YU; SOT-363_SC-70-6
U11: FM25CL64B
U12: MCP6001-OT; SOT-23-5
Y1: 32768Hz; Crystal_DS26_D2.0mm_L6.0mm_Vertical

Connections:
+3.3VA: C4.2, C14.2, JP8.1 (A), U5.8 (VOUT), U8.1, U12.5 (V+)
+3V3: C11.2, C12.2, C13.2, D3.2, J5.1, J6.1, JP4.1 (A), JP6.2 (B), JP8.2 (B), JP9.1 (A), U2.7 (VDD), U2.8 (VDD), U4.8 (VCC), U6.6 (VDDIO), U6.8 (VDD), U9.5 (VDD), U11.3 (WP#), U11.7 (HOLD#), U11.8 (VCC)
+12V: C1.1, J1.6, JP3.1 (A), PS1.4 (+Vout), R8.2, R17.1, U5.1 (VS), U7.1 (EN), U7.2 (VIN), U10.4 (C2)
AD: R13.2, R14.2, U1.10 (P0.30/AIN6)
AU_BCLK: U1.40 (P1.04), U2.16 (BCLK)
AU_DIN: U1.38 (P1.02), U2.1 (DIN)
AU_EN: U1.36 (P1.00), U2.4 (SD_MODE)
AU_LRCLK: U1.42 (P1.06), U2.14 (LRCLK)
BME_CS: U1.3 (P0.03/AIN1), U6.2 (CSB)
BS: C9.2, D2.2 (A), U1.15 (P0.05/AIN3)
BUS: C8.1, J1.4, R8.1, U5.4 (LIN)
BUS_EN: U1.14 (P0.06), U5.2 (EN)
BUS_RX: U1.34 (P0.22), U5.5 (RxD)
BUS_TX: U1.16 (P0.08), U5.6 (TxD)
BUTTON: SW1.4 (S1), U1.26 (P0.18)
DISP_CS: U1.17 (P1.09), U9.8 (CS#)
EN_12V: R17.2, R18.1, U1.9 (P0.31/AIN7), U10.2 (B1)
EXT1: J1.2, JP1.1 (A), R11.1, R15.2
EXT2: J1.1, JP2.1 (A), R12.1, R16.1
FERAM_CS: U1.2 (P1.10), U11.1 (CS#)
G1: D1.3, D6.2 (A), D8.1 (K), J10.2
G2: D4.3, D7.2 (A), D9.1 (K), J10.1
GENERATOR: C15.2, D1.2, D4.2, D5.1 (K), D6.1 (K), D7.1 (K), JP10.1 (A), U1.23 (VDDH)
GND: BT1.2 (-), C1.2, C2.2, C3.2, C4.1, C5.1, C6.1, C8.2, C9.1, C10.2, C11.1, C12.1, C13.1, C14.1, C15.1, C16.2, C17.2, D1.1, D2.1 (K), D4.1, D5.2 (A), D8.2 (A), D9.2 (A), J1.5, J3.1, J4.5 (GND), J4.6 (Shield), J5.2, J6.2, JP4.3 (B), JP5.2 (B), PS1.3 (-Vout), R2.2, R4.1, R10.2, R14.1, R18.2, SW1.2 (C), SW1.5 (S2), SW1.6 (SH), U1.5 (GND), U1.21 (GND), U1.24 (GND), U2.3 (GND), U2.11 (GND), U2.15 (GND), U2.17 (EP), U3.2, U4.5 (GND), U5.3 (GND), U5.9 (EP), U6.1 (GND), U6.7 (GND), U7.3 (GND), U7.9 (GND), U8.3, U9.1 (GND), U9.2 (VLSS), U9.3 (VSS), U9.6 (BS1), U9.7 (BS2), U9.11 (R/W#), U9.12 (E), U9.16 (D3), U9.17 (D4), U9.18 (D5), U9.19 (D6), U9.20 (D7), U9.24 (GND), U9.25 (PAD), U9.26 (PAD), U10.1 (E1), U11.4 (VSS), U12.2 (V-)
H: R3.1, U1.22 (P0.07)
H1: J2.5, U3.4
H2: J2.4, U3.6
IN: J1.3, R13.1
L: J2.3, PS1.2 (AC/N), RV1.2
MD_N: C6.2, R5.1, U1.4 (P0.28/AIN4)
MD_P: C7.2, R6.2, R7.2, U1.18 (P0.04/AIN2), U12.1
N: J2.2, PS1.1 (AC/L), RV1.1
unnamed: BT1.1 (+), D3.1
unnamed: C2.1, JP6.1 (A), R1.1, U7.4 (VOUT), U7.5 (VOUT)
unnamed: C3.1, U9.22 (VCOMH)
unnamed: C5.2, R4.2, U8.2, U12.3 (+)
unnamed: C7.1, R5.2, R6.1, R7.1, U12.4 (-)
unnamed: C10.1, D3.3, JP9.2 (B), JP10.2 (B), U1.19 (VDD)
unnamed: C16.1, U1.11 (P0.00/XL1), Y1.1
unnamed: C17.1, U1.13 (P0.01/XL2), Y1.2
unnamed: J7.1, U2.9 (OUTP)
unnamed: J7.2, U2.10 (OUTN)
unnamed: J8.1, U1.41 (P0.09/NFC1)
unnamed: J8.2, U1.43 (P0.10/NFC2)
unnamed: J9.1, U1.1 (P1.11)
unnamed: JP1.2 (B), R15.1, U4.6 (A)
unnamed: JP2.2 (B), R16.2, U4.7 (B)
unnamed: JP3.2 (C), U9.23 (VCC)
unnamed: JP3.3 (B), U10.3 (C2)
unnamed: JP4.2 (C), U2.2 (GAIN)
unnamed: JP5.1 (A), U4.2 (~RE)
unnamed: R1.2, R2.1, U7.6 (FB)
unnamed: R3.2, U3.1
unnamed: R10.1, U9.21 (IREF)
unnamed: U10.5 (B2), U10.6 (C1)
PE: J2.1
PIN1: J6.3, R11.2, U1.32 (P0.20), U4.3 (DE)
PIN2: J6.4, R12.2, U1.30 (P0.17), U4.1 (RO)
PIN3: J6.5, U1.28 (P0.15), U4.4 (DI)
PIN4: J6.6, U1.20 (P0.12)
POTI_A: SW1.1 (A), U1.33 (P0.13)
POTI_B: SW1.3 (B), U1.35 (P0.24)
RESET: U1.12 (P0.26), U5.7 (RSTN), U9.9 (RES#)
SPI_MISO: U1.8 (P0.29/AIN5), U6.5 (SDO), U9.10 (D/C#), U11.2 (SO)
SPI_MOSI: U1.6 (P1.13), U6.3 (SDI), U9.14 (D1/MOSI), U11.5 (SI)
SPI_SCK: U1.7 (P0.02/AIN0), U6.4 (SCK), U9.13 (D0/SCK), U11.6 (SCK)
SWDCLK: J5.4, U1.39 (SWDCLK)
SWDIO: J5.3, U1.37 (SWDIO)
USB_D+: J4.3 (D+), U1.31 (USB_D+)
USB_D-: J4.2 (D-), U1.29 (USB_D-)
USB_VBUS: J4.1 (VBUS), U1.27 (VBUS)

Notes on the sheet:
FeRam
R = (3.3V - 1.4V) / 15mA
Vout = 0.8V * (1 + R1/R2) R1 = (Vout / 0.8V - 1) * R2
10µA, 1V
Input
Bus
Debug
Brightness Sensor
RS485
Extension
Rotary Encoder
R = (12V - 3V) / 10uA
Power
Speaker
12V -> 3.3V
Voltage Monitor
Motion Detector
Audio
Air Sensor
Heating
Display (SSD1309)

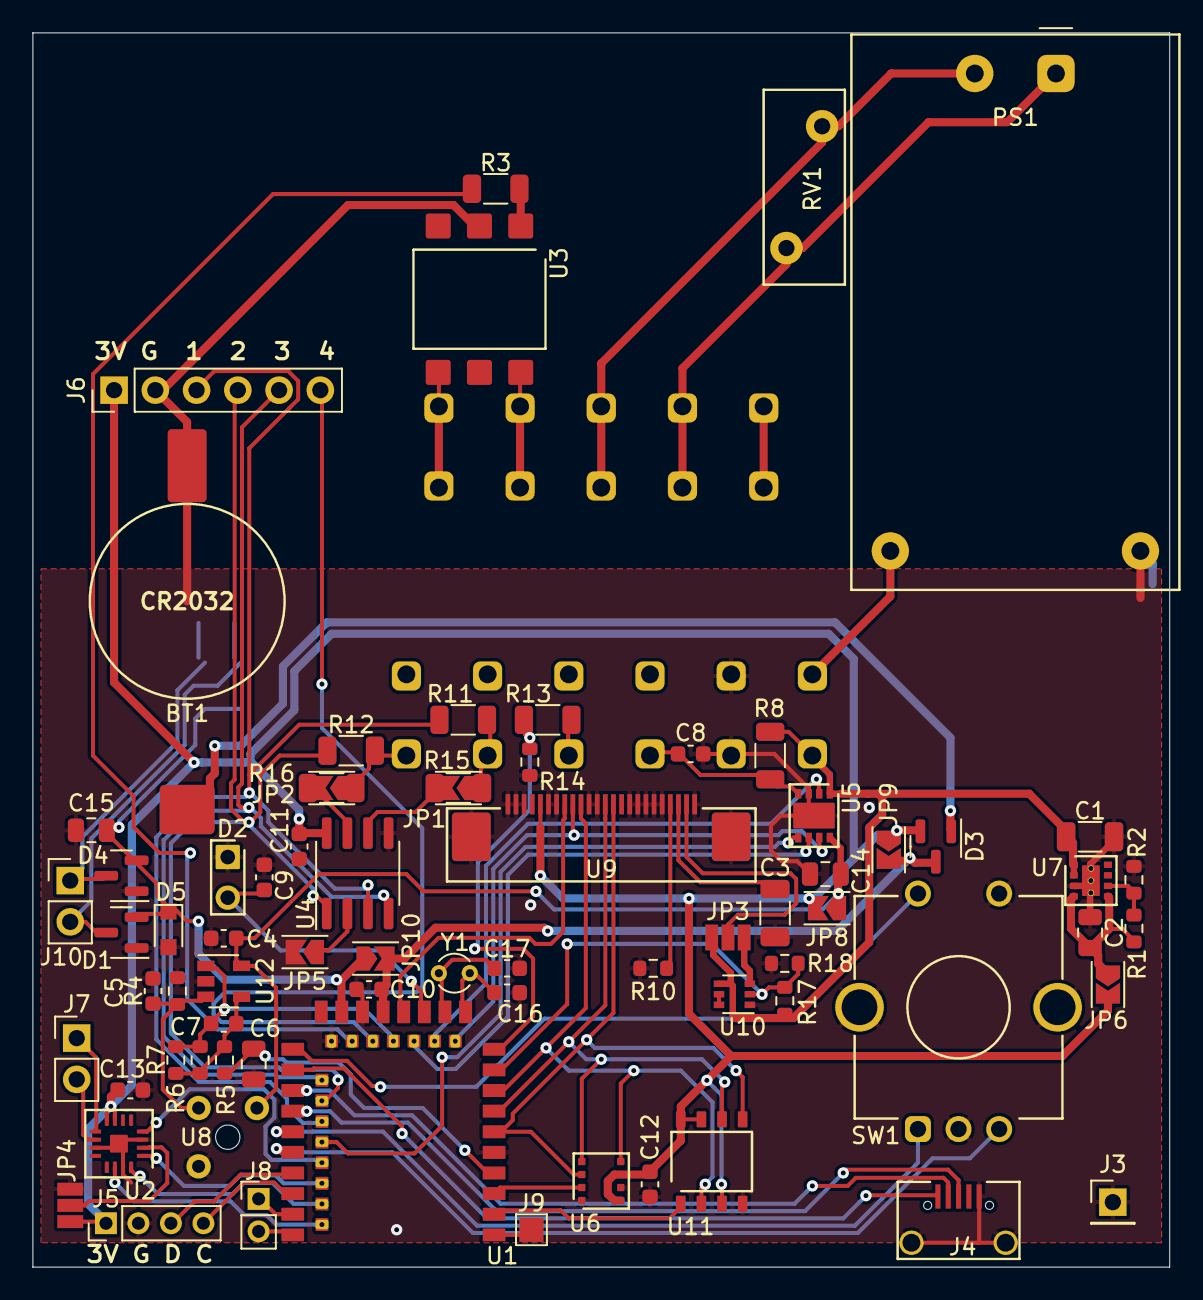
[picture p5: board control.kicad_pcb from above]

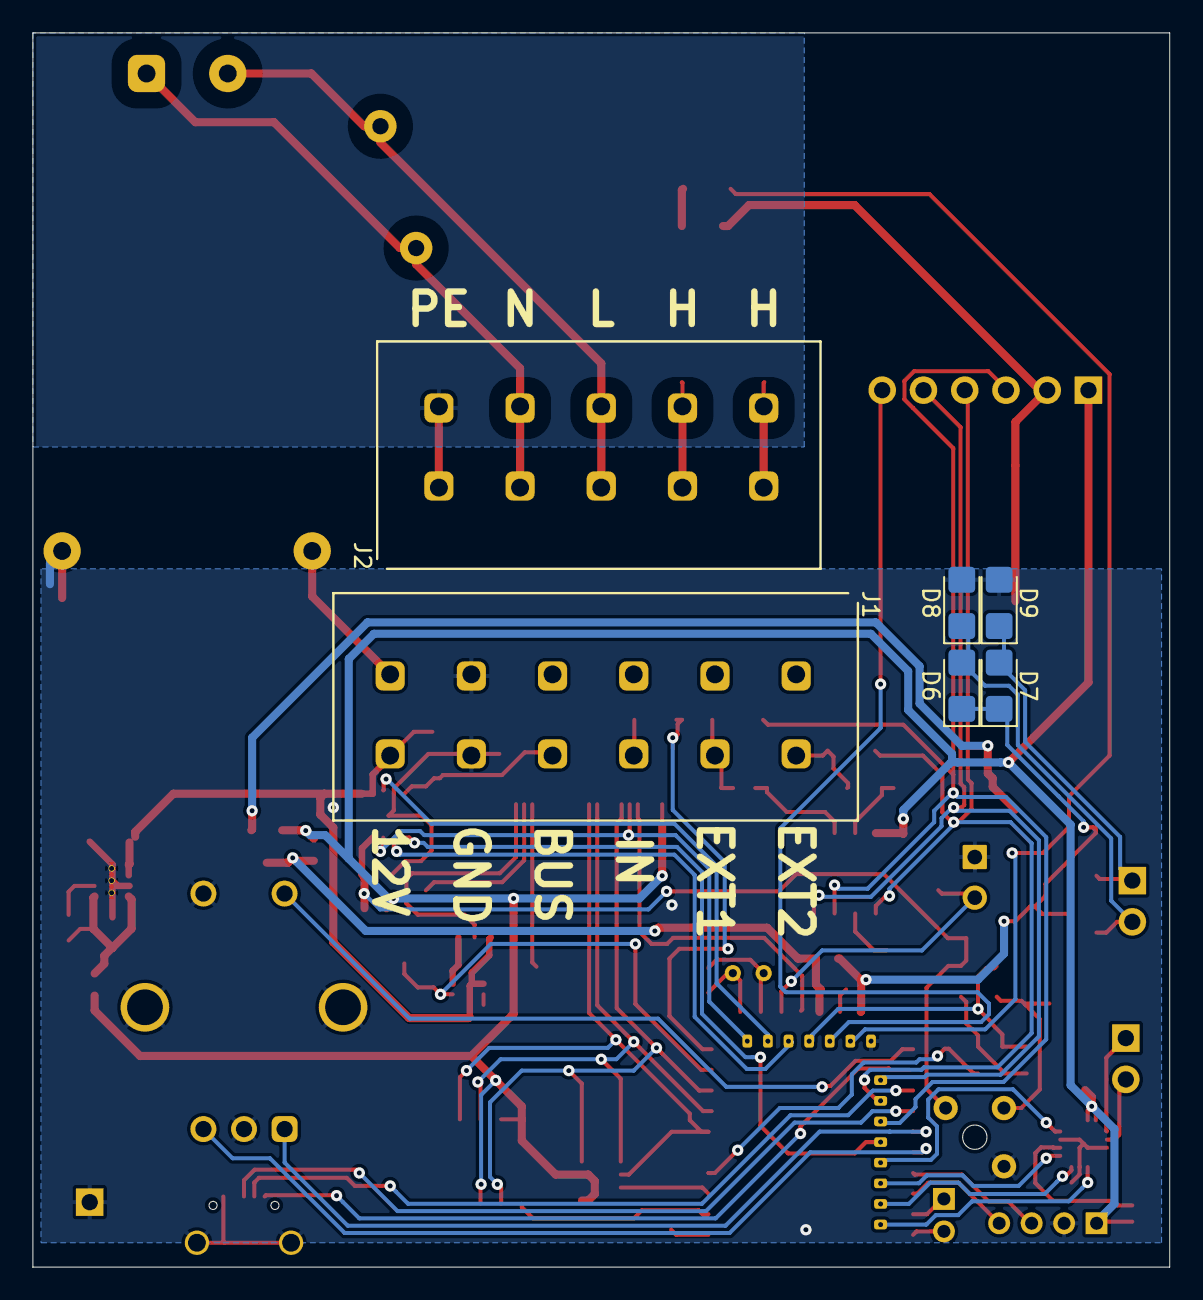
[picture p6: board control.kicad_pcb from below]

Board: 2 copper layers, 70.0 x 76.0 mm, 79 parts (6 on the bottom side), 70 nets.

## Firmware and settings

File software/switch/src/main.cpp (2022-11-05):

#include <Timer.hpp>
#include <Input.hpp>
#include <Output.hpp>
#include <Debug.hpp>
#include <BusNode.hpp>
#include <Loop.hpp>
#include <Terminal.hpp>
#include <SystemTime.hpp>
#include <bus.hpp>
#include <Queue.hpp>
#include <StringOperators.hpp>
#include <boardConfig.hpp>


/*
	Commission: Press all 4 buttons at the same time (emulator: press on center) and release again

	Configure: Press all 4 buttons at the same time (emulator: press on center), then release some buttons for
	the desired configuration and keep the remaining buttons held for at least 3 seconds.
	Buttons on left (A) side:
		Upper (A0): Light
		Lower (A1): Double Light
		Both (A0+A1): Blind
	Buttons on right (B) side:
		Upper (B0): Light
		Lower (B1): Double Light
		Both (B0+B1): Blind
*/

// todo: set individual device id before flashing
uint32_t deviceId = 0x12345678;

// time of relay to perform state change
constexpr SystemDuration RELAY_TIME = 10ms;

// plug types
constexpr auto ROCKER = bus::PlugType::TERNARY_ROCKER_OUT;
constexpr auto LIGHT = bus::PlugType::BINARY_POWER_LIGHT_IN;
constexpr auto BLIND = bus::PlugType::TERNARY_OPENING_BLIND_IN;

// plug lists for the different modes
const bus::PlugType plugsLight[] = {ROCKER, LIGHT};
const bus::PlugType plugsDoubleLight[] = {ROCKER, LIGHT, LIGHT};
const bus::PlugType plugsBlind[] = {ROCKER, BLIND};
const int plugCounts[4] = {0, 2, 3, 2};

const Array<bus::PlugType const> plugs[] = {
	{},
	plugsLight,
	plugsDoubleLight,
	plugsBlind
};

// encryption
constexpr int micLength = 4;


class Switch {
public:

	Switch() {
		int size;

		// load mode of channels A and B
		size = sizeof(Modes);
		this->drivers.storage.readBlocking(ID_MODES, size, &this->modes);
		if (size != sizeof(Modes) || this->modes.a < Mode::LIGHT || this->modes.a > Mode::BLIND)
			this->modes.a = Mode::LIGHT;
		if (size != sizeof(Modes) || this->modes.b < Mode::LIGHT || this->modes.b > Mode::BLIND)
			this->modes.b = Mode::LIGHT;

		// load commissioning
		size = sizeof(Commissioning);
		this->drivers.storage.readBlocking(ID_COMMISSIONING, size, &this->commissioning);
		if (size != sizeof(Commissioning))
			this->commissioning.address = -1;

		// load security counters
		size = 4;
		this->drivers.counters.readBlocking(ID_NODE_SECURITY_COUNTER, size, &this->nodeSecurityCounter);
		if (size != 4)
			this->nodeSecurityCounter = 0;
		size = 4;
		this->drivers.counters.readBlocking(ID_MASTER_SECURITY_COUNTER, size, &this->masterSecurityCounter);
		if (size != 4)
			this->masterSecurityCounter = 0;

		// start coroutines
		checkButtons();
		send();
		receive();
		updateRelays();
	}

	Coroutine checkButtons() {
		while (true) {
			int index;
			bool state;

			// wait until trigger detected on input
			co_await Input::trigger(0xf, 0xf, index, state);
			//Terminal::out << "trigger " << dec(index) << ' ' << dec(int(state)) << '\n';

			// configure when at least one button was held for 3s after all were pressed
			if (this->configure && Timer::now() > this->allTime + 3s) {
				// use button state as configuration
				int a = this->buttons & 3;
				if (a != 0)
					this->modes.a = Mode(a);
				int b = this->buttons >> 2;
				if (b != 0)
					this->modes.b = Mode(b);
				this->configure = false;
				Terminal::out << "config " << dec(this->modes.a) << ' ' << dec(this->modes.b) << '\n';

				// write modes to flash
				this->drivers.storage.writeBlocking(ID_MODES, sizeof(Modes), &this->modes);
			}

			// update button state (only needed for configuration and commissioning)
			uint8_t mask = 1 << index;
			this->buttons = (this->buttons & ~mask) | (uint8_t(state) << index);

			// check if all buttons are pressed
			if (this->buttons == 0x0f) {
				this->allTime = Timer::now();
				this->commission = true;
				this->configure = true;
				//Terminal::out << "all\n";
			}

			// commission when all buttons were released
			if (this->commission && this->buttons == 0) {
				//Terminal::out << "enumerate\n";
				this->commission = false;
				this->configure = false;

				// switch to standalone mode
				this->commissioning.address = -1;

				// store to flash (remove entry)
				this->drivers.storage.eraseBlocking(ID_COMMISSIONING);

				// add enumerate command to send queue
				this->sendQueue.addBack(SendElement{255, 255});
				this->sendBarrier.resumeFirst();
			}


			if (this->commissioning.address == -1) {
				// standalone mode: A and B channel each control one relay with 0 = off and 1 = on
				if ((index & 2) == 0) {
					// A
					switch (this->modes.a) {
					case Mode::LIGHT:
						if (state) {
							this->relays &= ~0x11;
							this->relays |= 1 - index;
						}
						break;
					case Mode::DOUBLE_LIGHT:
						this->relays &= ~0x10 << index;
						if (state)
							this->relays ^= 1 << index;
						break;
					case Mode::BLIND:
						if (state) {
							this->relays &= ~0x33;
							this->relays |= 1 << index;
						}
						break;
					default:
						break;
					}
				} else {
					// B
					index &= 1;
					switch (this->modes.b) {
					case Mode::LIGHT:
						if (state) {
							this->relays &= ~0x44;
							this->relays |= (1 - index) << 2;
						}
						break;
					case Mode::DOUBLE_LIGHT:
						this->relays &= ~0x40 << index;
						if (state)
							this->relays ^= (1 << index) << 2;
						break;
					case Mode::BLIND:
						if (state) {
							this->relays &= ~0xcc;
							this->relays |= (1 << index) << 2;
						}
						break;
					default:
						break;
					}
				}
				this->relayBarrier.resumeFirst();
			} else {
				// bus mode: report state change on bus

				// plug index (plugs of channel B come after plugs of channel A)
				uint8_t plugIndex = (index & 2) == 0 ? 0 : plugCounts[int(this->modes.a)];

				// value
				uint8_t value = int(state) << (index & 1);

				// add to send queue
				this->sendQueue.addBack(SendElement{plugIndex, value});
				this->sendBarrier.resumeFirst();
			}
		}
	}

	Coroutine send() {
		uint8_t sendData[64];
		while (true) {
			if (this->sendQueue.isEmpty()) {
				// wait until someone fills the queue
				co_await this->sendBarrier.wait();
			}

			// get element from queue
			auto const &element = this->sendQueue[0];

			bus::MessageWriter w(sendData);
			w.setHeader();

			if (element.plugIndex == 255) {
				if (element.value == 255) {
					// send enumerate message

					// prefix with zero
					w.u8(0);

					// encoded device id
					w.id(deviceId);

					// protocol version
					w.u8(0);

					// number of endpoints
					w.u8(1);

					// encrypt
					w.setMessage();
					Nonce nonce(deviceId, 0);
					w.encrypt(micLength, nonce, bus::defaultAesKey);

					this->nodeSecurityCounter = 0;
					this->drivers.counters.writeBlocking(ID_NODE_SECURITY_COUNTER, 4, &this->nodeSecurityCounter);
				} else {
					// send attribute
					auto attribute = bus::Attribute(element.value);

					// encoded address
					w.address(this->commissioning.address);

					// security counter
					w.u32L(this->nodeSecurityCounter);

					// set start of message
					w.setMessage();

					// "escaped" endpoint index
					w.u8(255);
					w.u8(0);

					// attribute
					w.e8(attribute);

					switch (attribute) {
					case bus::Attribute::MODEL_IDENTIFIER:
						w.string("Switch");
						break;
					case bus::Attribute::PLUG_LIST:
						// list of plugs
						// list of plugs of part A and B
						w.data16L(plugs[int(this->modes.a)]);
						w.data16L(plugs[int(this->modes.b)]);
						break;
					default:;
					}

					// encrypt
					Nonce nonce(this->commissioning.address, this->nodeSecurityCounter);
					w.encrypt(micLength, nonce, this->commissioning.aesKey);

					// increment security counter
					++this->nodeSecurityCounter;
					this->drivers.counters.writeBlocking(ID_NODE_SECURITY_COUNTER, 4, &this->nodeSecurityCounter);
				}
			} else {
				// send plug message

				// encoded address
				w.address(this->commissioning.address);

				// security counter
				w.u32L(this->nodeSecurityCounter);

				// set start of message
				w.setMessage();

				// endpoint index
				w.u8(0);

				// plug index
				w.u8(element.plugIndex);

				// value
				w.u8(element.value);

				// encrypt
				Nonce nonce(this->commissioning.address, this->nodeSecurityCounter);
				w.encrypt(micLength, nonce, this->commissioning.aesKey);

				// increment security counter
				++this->nodeSecurityCounter;
				this->drivers.counters.writeBlocking(ID_NODE_SECURITY_COUNTER, 4, &this->nodeSecurityCounter);
			}
			this->sendQueue.removeFront();

			co_await this->drivers.busNode.send(w.getLength(), sendData);
		}
	}

	Coroutine receive() {
		uint8_t receiveData[64];
		while (true) {
            // receive from bus
			int length = array::count(receiveData);
			co_await this->drivers.busNode.receive(length, receiveData);

			// decode received message
			bus::MessageReader r(length, receiveData);
			r.setHeader();

			// check for command prefix (0)
			if (r.peekU8() == 0) {
				// received command message
				r.u8();
				if (r.u8() == 0) {
					// 0 0: commission

					// get device id
					auto id = r.u32L();

					// check message integrity code (mic)
					r.setMessageFromEnd(micLength);
					Nonce nonce(id, 0);
					if (!r.decrypt(micLength, nonce, bus::defaultAesKey))
						continue;

					// get address
					auto address = r.u8();

					// check if device id is the device id of this node
					if (id == deviceId) {
						// clear master security counter
						this->masterSecurityCounter = 0;
						this->drivers.counters.writeBlocking(ID_MASTER_SECURITY_COUNTER, 4, &this->masterSecurityCounter);

						// set address
						this->commissioning.address = address;
						//Terminal::out << "commissioned on address " << dec(address) << '\n';

						// set key
						setKey(this->commissioning.aesKey, r.data8<16>());

						// store to flash
						this->drivers.storage.writeBlocking(ID_COMMISSIONING, sizeof(Commissioning), &this->commissioning);
					} else if (this->commissioning.address == address) {
						// the address of this node now gets assigned to another node: decommission
						// is probably a security hole
						/*
						// switch to standalone mode
						this->commissioning.address = -1;

						// store to flash (remove entry)
						this->drivers.storage.eraseBlocking(ID_COMMISSIONING);
						*/
					}
				}
			} else {
				// received data message: check address
				int addr = r.address();
				if (addr != this->commissioning.address)
					continue;

				// security counter
				uint32_t securityCounter = r.u32L();

				// check security counter
				if (securityCounter <= this->masterSecurityCounter) {
					Terminal::out << "M security counter error " << dec(securityCounter) << " <= " << dec(this->masterSecurityCounter) << '\n';
					//continue;
				} else {
					//Terminal::out << "M security counter ok " << dec(securityCounter) << " > " << dec(this->masterSecurityCounter) << '\n';
				}
				this->masterSecurityCounter = securityCounter;
				this->drivers.counters.writeBlocking(ID_MASTER_SECURITY_COUNTER, 4, &this->masterSecurityCounter);

				// decrypt
				r.setMessage();
				Nonce nonce(this->commissioning.address, securityCounter);
				if (!r.decrypt(micLength, nonce, this->commissioning.aesKey))
					break;

				// get endpoint index (255 for read attribute)
				uint8_t endpointIndex = r.u8();
				if (endpointIndex == 255) {
					// attribute
					endpointIndex = r.u8();
					auto attribute = r.e8<bus::Attribute>();
					if (r.atEnd() && endpointIndex == 0) {
						this->sendQueue.addBack(SendElement{255, uint8_t(attribute)});
						this->sendBarrier.resumeFirst();
					}
				} else if (endpointIndex == 0) {
					// plug
					uint8_t plugIndex = r.u8();
					int plugCountA = plugCounts[int(this->modes.a)];
					int plugCountB = plugCounts[int(this->modes.b)];
					if (plugIndex >= plugCountA + plugCountB)
						break;

					bus::PlugType plugType;
					int relayIndex;
					if (plugIndex < plugCountA) {
						plugType = plugs[int(this->modes.a)][plugIndex];
						relayIndex = plugIndex == 2 ? 1 : 0;
					} else {
						plugIndex -= plugCountA;
						plugType = plugs[int(this->modes.b)][plugIndex];
						relayIndex = plugIndex == 2 ? 3 : 2;
					}

					int &state = this->outputStates[relayIndex];

					switch (plugType) {
					case LIGHT: {
						// 0: off, 1: on, 2: toggle
						uint8_t s = r.u8();
						if (s < 2)
							state = s;
						else if (s == 2)
							state ^= 1;
						this->relays &= ~(0x11 << relayIndex);
						this->relays |= state << relayIndex;
						this->relayBarrier.resumeFirst();
						break;
					}
					case BLIND: {
						// 0: inactive, 1: up, 2: down
						uint8_t s = r.u8();
						state = s <= 2 ? s : 0;
						this->relays &= ~(0x33 << relayIndex);
						this->relays |= state << relayIndex;
						this->relayBarrier.resumeFirst();
						break;
					}
					default:
						break;
					}
				}
			}
		}
	}

	Coroutine updateRelays() {
		// current state of 4 relays A0, A1, B0, B1, upper 4 bit indicate "unknown state" after power-on
		uint8_t relays = 0xf0;
		
		while (true) {
			while (this->relays == relays) {
				// wait until relays change
				co_await this->relayBarrier.wait();
			}

			// repat until all relays have been changed
			while (this->relays != relays) {
				//Terminal::out << "relays " << hex(this->relays) << " " << hex(relays) << "\n";
				uint8_t change = this->relays ^ relays;

				// check if A0 or A1 need to be changed
				uint8_t ax = 0;
				uint8_t ay = 0;
				uint8_t az = 0;
				if (change & 0x33) {
					uint8_t a0 = this->relays & 1;
					uint8_t a1 = (this->relays >> 1) & 1;

					if ((change & 0x11) != 0 && ((change & 0x22) == 0 || a0 == 0 || a0 == a1)) {
						ax = (a0 ^ 1) | a0 << 1;
						ay = ax ^ 3;
						relays = (relays & ~0x11) | (this->relays & 0x11);
					}
					if ((change & 0x22) != 0 && ((change & 0x11) == 0 || a1 == 0 || a1 == a0)) {
						az = (a1 ^ 1) | a1 << 1;
						ay = az ^ 3;
						relays = (relays & ~0x22) | (this->relays & 0x22);
					}
				}
			
				// check if B0 or B1 need to be changed
				uint8_t bx = 0;
				uint8_t by = 0;
				uint8_t bz = 0;
				if (change & 0xcc) {
					uint8_t b0 = (this->relays >> 2) & 1;
					uint8_t b1 = (this->relays >> 3) & 1;

					if ((change & 0x44) != 0 && ((change & 0x88) == 0 || b0 == 0 || b0 == b1)) {
						bx = (b0 ^ 1) | b0 << 1;
						by = bx ^ 3;
						relays = (relays & ~0x44) | (this->relays & 0x44);
					}
					if ((change & 0x88) != 0 && ((change & 0x44) == 0 || b1 == 0 || b1 == b0)) {
						bz = (b1 ^ 1) | b1 << 1;
						by = bz ^ 3;
						relays = (relays & ~0x88) | (this->relays & 0x88);
					}
				}
				//Terminal::out << "ab " << dec(ax) << dec(ay) << dec(az) << " " << dec(bx) << dec(by) << dec(bz) << "\n";

				// build 16 bit word for relay driver
				uint16_t word = 0x8000 // enable
					| (ax << (MPQ6526_MAPPING[0] * 2 + 1))
					| (ay << (MPQ6526_MAPPING[1] * 2 + 1))
					| (az << (MPQ6526_MAPPING[2] * 2 + 1))
					| (bx << (MPQ6526_MAPPING[3] * 2 + 1))
					| (by << (MPQ6526_MAPPING[4] * 2 + 1))
					| (bz << (MPQ6526_MAPPING[5] * 2 + 1));
				//Terminal::out << "spi " << hex(word) << "\n";
				co_await this->drivers.relayDriver.transfer(1, &word, 0, nullptr);

				// wait some time until relay contacts react
				co_await Timer::sleep(RELAY_TIME);
			}

			// switch off all half bridges
			uint16_t word = 0;
			co_await this->drivers.relayDriver.transfer(1, &word, 0, nullptr);
		}
	}

	// platform dependent drivers
	SwitchDrivers drivers;

	// mode of channel A and B
	static constexpr int ID_MODES = 1;
	enum class Mode : uint8_t {
		LIGHT = 1,
		DOUBLE_LIGHT = 2,
		BLIND = 3,
	};
	struct Modes {
		Mode a;
		Mode b;
	};
	Modes modes;

	// commissioning and configuration
	static constexpr int ID_COMMISSIONING = 2;
	struct Commissioning {
		int address;
		AesKey aesKey;
	};
	Commissioning commissioning;
	uint8_t buttons = 0;
	SystemTime allTime;
	bool commission = false;
	bool configure = false;

	// security counters
	static constexpr int ID_NODE_SECURITY_COUNTER = 1;
	static constexpr int ID_MASTER_SECURITY_COUNTER = 2;
	uint32_t nodeSecurityCounter;
	uint32_t masterSecurityCounter;

	// sending over bus
	struct SendElement {uint8_t plugIndex; uint8_t value;};
	Queue<SendElement, 8> sendQueue;
	Barrier<> sendBarrier;

	// relays
	int outputStates[4] = {};
	uint8_t relays = 0xf0;
	Barrier<> relayBarrier;
};


int main() {
	Loop::init();
	Output::init(); // for debug signals on pins
	Input::init();
	Timer::init();

	Switch s;

	Loop::run();
}

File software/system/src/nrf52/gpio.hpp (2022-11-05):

#pragma once

#include "nrf52.hpp"


namespace gpio {

// ports
constexpr int P0(int index) { return index; }

constexpr int P1(int index) { return 32 + index; }

constexpr NRF_GPIO_Type *getPort(int pin) { return (NRF_GPIO_Type *) (pin < 32 ? NRF_P0_BASE : NRF_P1_BASE); }

// pin is disconnected
constexpr int DISCONNECTED = 0xffffffff;


enum class Drive {
	S0S1 = 0, // Standard '0', standard '1'
	H0S1 = 1, // High drive '0', standard '1'
	S0H1 = 2, // Standard '0', high drive '1'
	H0H1 = 3, // High drive '0', high drive '1'
	D0S1 = 4, // Disconnect '0' standard '1' (normally used for wired-or connections)
	D0H1 = 5, // Disconnect '0', high drive '1' (normally used for wired-or connections)
	S0D1 = 6, // Standard '0', disconnect '1' (normally used for wired-and connections)
	H0D1 = 7  // High drive '0', disconnect '1' (normally used for wired-and connections)
};

enum class Pull {
	DISABLED = 0,
	DOWN = 1, // Pull down on pin
	UP = 3 // Pull up on pin
};


// analog
// ------

inline void configureAnalog(int pin) {
	auto port = getPort(pin);
	auto &config = port->PIN_CNF[pin & 31];
	config = N(GPIO_PIN_CNF_DIR, Input)
		| N(GPIO_PIN_CNF_INPUT, Disconnect)
		| N(GPIO_PIN_CNF_PULL, Disabled);
}


// input
// -----

// configure input
inline void configureInput(int pin, Pull pull = Pull::DISABLED) {
	auto port = getPort(pin);
	port->PIN_CNF[pin & 31] =
		N(GPIO_PIN_CNF_INPUT, Connect)
			| V(GPIO_PIN_CNF_PULL, int(pull));
}

// for boardConfig.hpp
struct InputConfig {
	int pin; // port and plugIndex
	Pull pull;
	bool invert;
};

// add input config, pin can also be an output (used in input.cpp)
inline void addInputConfig(InputConfig const &config) {
	auto port = getPort(config.pin);
	int pos = config.pin & 31;

	// configure
	auto &PIN_CNF = port->PIN_CNF[pos];
	uint32_t c = PIN_CNF;
	c = (c & ~(GPIO_PIN_CNF_INPUT_Msk | GPIO_PIN_CNF_PULL_Msk))
		| N(GPIO_PIN_CNF_INPUT, Connect)
		| V(GPIO_PIN_CNF_PULL, int(config.pull));
	PIN_CNF = c;
}

// read input value
inline bool readInput(int pin) {
	auto port = getPort(pin);
	return (port->IN & (1 << (pin & 31))) != 0;
}


// output
// ------

// configure output
inline void configureOutput(int pin, Pull pull = Pull::DISABLED, Drive drive = Drive::S0S1) {
	auto port = getPort(pin);
	port->PIN_CNF[pin & 31] =
		N(GPIO_PIN_CNF_DIR, Output)
			| V(GPIO_PIN_CNF_DRIVE, int(drive))
			| V(GPIO_PIN_CNF_PULL, int(pull))
			| N(GPIO_PIN_CNF_INPUT, Disconnect);
}

// for boardConfig.hpp
struct OutputConfig {
	int pin; // port and plugIndex
	Pull pull;
	Drive drive;
	bool enabled;
	bool invert;
	bool initialValue;
};

// add output config, pin can also be an input (used in output.cpp)
inline void addOutputConfig(OutputConfig const &config) {
	auto port = getPort(config.pin);
	int pos = config.pin & 31;

	// set initial value
	if (config.initialValue != config.invert)
		port->OUTSET = 1 << pos;

	// configure
	auto &PIN_CNF = port->PIN_CNF[pos];
	uint32_t c = PIN_CNF;
	c = (c & ~(GPIO_PIN_CNF_DRIVE_Msk | GPIO_PIN_CNF_PULL_Msk | GPIO_PIN_CNF_DIR_Msk))
		| V(GPIO_PIN_CNF_PULL, int(config.pull))
		| V(GPIO_PIN_CNF_DRIVE, int(config.drive));
	if (config.enabled)
		c |= N(GPIO_PIN_CNF_DIR, Output);
	PIN_CNF = c;
}

// enable output
inline void enableOutput(int pin, bool enabled) {
	auto port = getPort(pin);
	uint32_t config = port->PIN_CNF[pin & 31];
	if (enabled)
		config |= N(GPIO_PIN_CNF_DIR, Output);
	else
		config &= ~GPIO_PIN_CNF_DIR_Msk;
	port->PIN_CNF[pin & 31] = config;
}

// set output value
inline void setOutput(int pin, bool value) {
	auto port = getPort(pin);
	if (value)
		port->OUTSET = 1 << (pin & 31);
	else
		port->OUTCLR = 1 << (pin & 31);
}

// toggle output value
inline void toggleOutput(int pin) {
	auto port = getPort(pin);
	uint32_t bit = 1 << (pin & 31);
	bool value = (port->OUT & bit) == 0;
	if (value)
		port->OUTSET = bit;
	else
		port->OUTCLR = bit;
}

} // namespace gpio

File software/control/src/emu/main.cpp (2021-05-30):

#include "RoomControl.hpp"
#include "Gui.hpp"
#include <flash.hpp>
#include <emu/spi.hpp>
#include <display.hpp>
#include <radio.hpp>
#include <emu/loop.hpp>
#include <iostream>
#include <fstream>
#include <vector>
#include <thread>
#include <iterator>



// extension to emulated spi driver
namespace spi {
	// set temperature of emulated air sensor
	void setTemperature(float celsius);
	
	void doGui(Gui &gui, int &id) {
		// air sensor
		int temperature = gui.temperatureSensor(id++);
		if (temperature != -1)
			setTemperature(temperature / 20.0f - 273.15f);
		gui.newLine();
	}
}

// extension to emulated display driver
namespace display {
	// get dipslay contents into an 8 bit grayscale image
	void getDisplay(uint8_t *buffer);
}

// extension to emulated bus driver
namespace bus {
	void doGui(Gui &gui, int &id);
}

// extension to emulated radio driver
namespace radio {
	// poll usb device
	//void poll();

	// let the emulated radio receive some data
	void receiveData(int channel, uint8_t *data);

	// little endian 32 bit integer
	#define LE_INT32(value) uint8_t(value), uint8_t(value >> 8), uint8_t(value >> 16), uint8_t(value >> 24)

	static AesKey const defaultAesKey = {{0x5a696742, 0x6565416c, 0x6c69616e, 0x63653039, 0x166d75b9, 0x730834d5, 0x1f6155bb, 0x7c046582, 0xe62066a9, 0x9528527c, 0x8a4907c7, 0xf64d6245, 0x018a08eb, 0x94a25a97, 0x1eeb5d50, 0xe8a63f15, 0x2dff5170, 0xb95d0be7, 0xa7b656b7, 0x4f1069a2, 0xf7066bf4, 0x4e5b6013, 0xe9ed36a4, 0xa6fd5f06, 0x83c904d0, 0xcd9264c3, 0x247f5267, 0x82820d61, 0xd01eebc3, 0x1d8c8f00, 0x39f3dd67, 0xbb71d006, 0xf36e8429, 0xeee20b29, 0xd711d64e, 0x6c600648, 0x3801d679, 0xd6e3dd50, 0x01f20b1e, 0x6d920d56, 0x41d66745, 0x9735ba15, 0x96c7b10b, 0xfb55bc5d}};

	struct GreenPowerDevice {
		// the emulated radio channel the device sends on
		int channel;
		
		// device id
		uint32_t deviceId;

		// device security counter
		uint32_t counter;

		// device key
		AesKey key;
		
		// time for long button press
		std::chrono::steady_clock::time_point time;
		
		// last rocker state
		int lastRocker = 0;
	};

	GreenPowerDevice devices[1];

	// data used to initialize the green power devices
	struct GreenPowerDeviceData {
		uint32_t deviceId;
		uint32_t counter;
		uint8_t key[16];
	};

	GreenPowerDeviceData const deviceData[1] = {{
		0x12345678,
		0xfffffff0,
		{0xa0, 0xa1, 0xa2, 0xa3, 0xa4, 0xa5, 0xa6, 0xa7, 0xa8, 0xa9, 0xaa, 0xab, 0xac, 0xad, 0xae, 0xaf}}};

	void doGui(Gui &gui, int &id) {
		static bool inited = false;
		if (!inited) {
			inited = true;
			// init emulated green power devices (on user interface)
			for (int i = 0; i < array::size(devices); ++i) {
				GreenPowerDeviceData const &d = deviceData[i];
				GreenPowerDevice &device = devices[i];
				device.channel = 11; // default channel
				device.deviceId = d.deviceId;
				device.counter = d.counter;
				setKey(device.key, d.key);
			}
		}
		
		// emulated devices on user interface
		for (GreenPowerDevice &device : devices) {
			int rocker = gui.doubleRocker(id++);
			if (rocker != -1) {

				// time difference
				auto now = std::chrono::steady_clock::now();
				int ms = std::chrono::duration_cast<std::chrono::milliseconds>(now - device.time).count();
				device.time = now;

				if (ms > 3000 && rocker == 0) {
					// released after some time: commission
					if (device.lastRocker & 1)
						device.channel = 15;
					else if (device.lastRocker & 2)
						device.channel = 20;
					else if (device.lastRocker & 4)
						device.channel = 11;
					else if (device.lastRocker & 8)
						device.channel = 25;

					uint8_t data[] = {0,
						0x01, 0x08, uint8_t(device.counter), 0xff, 0xff, 0xff, 0xff, // mac header
						0x0c, // network header
						LE_INT32(device.deviceId), // deviceId
						0xe0, 0x02, 0xc5, 0xf2, // command and flags
						0xa0, 0xa1, 0xa2, 0xa3, 0xa4, 0xa5, 0xa6, 0xa7, 0xa8, 0xa9, 0xaa, 0xab, 0xac, 0xad, 0xae, 0xaf, // key
						LE_INT32(0), // mic
						LE_INT32(device.counter)}; // counter
					data[0] = array::size(data) - 1 + 2;

					// nonce
					Nonce nonce(device.deviceId, device.deviceId);

					// header is deviceId
					uint8_t const *header = data + 9;
					int headerLength = 4;
					
					// payload is key
					uint8_t *message = data + 17;
					
					encrypt(message, nonce, header, headerLength, message, 16, 4, defaultAesKey);

					radio::receiveData(device.channel, data);
				} else {
					uint8_t command = rocker != 0 ? 0 : 0x04;
					int r = rocker | device.lastRocker;
					if (r == 1)
						command |= 0x10;
					else if (r == 2)
						command |= 0x11;
					else if (r == 4)
						command |= 0x13;
					else if (r == 8)
						command |= 0x12;

					uint8_t data[] = {0,
						0x01, 0x08, uint8_t(device.counter), 0xff, 0xff, 0xff, 0xff, // mac header
						0x8c, 0x30, // network header
						LE_INT32(device.deviceId), // deviceId
						LE_INT32(device.counter), // counter
						command,
						0x00, 0x00, 0x00, 0x00}; // mic
					data[0] = array::size(data) - 1 + 2;
					
					// nonce
					Nonce nonce(device.deviceId, device.counter);

					// header is network header, deviceId, counter and command
					uint8_t const *header = data + 8;
					int headerLength = 11;

					// message: empty payload and mic
					uint8_t *message = data + 19;

					encrypt(message, nonce, header, headerLength, message, 0, 4, device.key);

					radio::receiveData(device.channel, data);
				}
				++device.counter;
				device.lastRocker = rocker;
			}
		}
		
		gui.newLine();
	}
}


static void errorCallback(int error, const char* description)
{
    fprintf(stderr, "Error: %s\n", description);
}

static void keyCallback(GLFWwindow* window, int key, int scancode, int action, int mods)
{
    if (key == GLFW_KEY_ESCAPE && action == GLFW_PRESS)
        glfwSetWindowShouldClose(window, GLFW_TRUE);
}

static void mouseCallback(GLFWwindow* window, int button, int action, int mods) {
 /*   if (button == GLFW_MOUSE_BUTTON_LEFT) {
        if(GLFW_PRESS == action)
            lbutton_down = true;
        else if(GLFW_RELEASE == action)
            lbutton_down = false;
    }

    if(lbutton_down) {
         // do your drag here
    }*/
}

struct DeviceData {
	uint32_t deviceId;
	String name;
	
	struct Component {
		RoomControl::Device::Component::Type type;
		uint8_t endpointIndex;
		uint8_t elementIndex;
		SystemDuration duration;
	};
	
	int componentCount;
	Component components[10];
};

// configuration for local devices (air sensor, brightness sensor, motion detector)
constexpr DeviceData localDeviceData[] = {
	{0x00000001, "tempsensor", 1, {
		{RoomControl::Device::Component::CELSIUS, 0, 0}
	}}
};
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

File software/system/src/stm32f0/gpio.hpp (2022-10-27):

#pragma once

#include "defs.hpp"
//#include <cstdint>


// data sheet: https://www.st.com/resource/en/datasheet/stm32f042f6.pdf
// refernece manual: https://www.st.com/resource/en/reference_manual/dm00031936-stm32f0x1stm32f0x2stm32f0x8-advanced-armbased-32bit-mcus-stmicroelectronics.pdf

namespace gpio {

// port pins
constexpr int PA(int index) { return index; }
constexpr int PB(int index) { return 16 + index; }
constexpr int PC(int index) { return 32 + index; }
constexpr int PF(int index) { return 80 + index; }

// get pointer to GPIO port for a given pin (e.g. GPIOA)
inline GPIO_TypeDef *getPort(int pin) { return (GPIO_TypeDef *)(GPIOA_BASE + (pin >> 4) * 0x00000400UL); }


enum class Mode {
	INPUT = 0,
	OUTPUT = 1,
	ALTERNATE = 2,
	ANALOG = 3
};

enum class Drive {
	PUSH_PULL = 0,
	OPEN_DRAIN = 1
};

enum class Speed {
	LOW = 0,
	MEDIUM = 1,
	HIGH = 3
};

enum class Pull {
	DISABLED = 0,
	UP = 1, // Pull up on pin
	DOWN = 2 // Pull down on pin
};


// set mode of a gpio
inline void setMode(int pin, Mode mode) {
	auto port = getPort(pin);
	int pos2 = (pin & 15) << 1;
	port->MODER = (port->MODER & ~(3 << pos2)) | int(mode);
}


// input
// -----

// for boardConfig.hpp
struct InputConfig {
	int pin; // port and index
	Pull pull;
	bool invert;
};

// add input config, pin can also be an output (used in input.cpp)
inline void addInputConfig(InputConfig const &config) {
	auto port = getPort(config.pin);
	int pos2 = (config.pin & 15) << 1;

	// enable peripheral clock for the port
	RCC->AHBENR = RCC->AHBENR | (1 << (RCC_AHBENR_GPIOAEN_Pos + (config.pin >> 4)));

	// configure
	// MODER is either input (reset state) or output (addOutputConfig() already called)
	port->PUPDR = (port->PUPDR & ~(3 << pos2)) | (int(config.pull) << pos2);
}

// read input value
inline bool readInput(int pin) {
	auto port = getPort(pin);
	return (port->IDR & (1 << (pin & 15))) != 0;
}


// output
// ------

inline void configureOutput(int pin, Pull pull = Pull::DISABLED, Speed speed = Speed::HIGH,
							Drive drive = Drive::PUSH_PULL) {
	auto port = getPort(pin);
	int pos = pin & 15;
	int pos2 = (pin & 15) << 1;

	// enable peripheral clock for the port
	RCC->AHBENR = RCC->AHBENR | (1 << (RCC_AHBENR_GPIOAEN_Pos + (pin >> 4)));

	// set drive, speed and pull
	port->PUPDR = (port->PUPDR & ~(3 << pos2)) | (int(pull) << pos2);
	port->OSPEEDR = (port->OSPEEDR & ~(3 << pos2)) | (int(speed) << pos2);
	port->OTYPER = (port->OTYPER & ~(1 << pos)) | (int(drive) << pos);

	// set mode to alternate function
	port->MODER = (port->MODER & ~(3 << pos2)) | (int(Mode::OUTPUT) << pos2);
}

// for boardConfig.hpp
struct OutputConfig {
	int pin; // port and index
	Pull pull;
	Speed speed;
	Drive drive;
	bool enabled;
	bool invert;
	bool initialValue;
};

// add output config, pin can also be an input (used in output.cpp)
inline void addOutputConfig(OutputConfig const &config) {
	auto port = getPort(config.pin);
	int pos = config.pin & 15;
	int pos2 = (config.pin & 15) << 1;

	// enable peripheral clock for the port
	RCC->AHBENR = RCC->AHBENR | (1 << (RCC_AHBENR_GPIOAEN_Pos + (config.pin >> 4)));

	// set initial value
	port->BSRR = 1 << (pos + (config.initialValue != config.invert ? 0 : 16));

	// configure
	port->PUPDR = (port->PUPDR & ~(3 << pos2)) | (int(config.pull) << pos2);
	port->OSPEEDR = (port->OSPEEDR & ~(3 << pos2)) | (int(config.speed) << pos2);
	port->OTYPER = (port->OTYPER & ~(1 << pos)) | (int(config.drive) << pos);
	if (config.enabled)
		port->MODER = port->MODER | (int(Mode::OUTPUT) << pos2);
}

// set output value
inline void setOutput(int pin, bool value) {
	auto port = getPort(pin);
	int pos = pin & 15;
	port->BSRR = 1 << (pos + (value ? 0 : 16));
}

// toggle output value
inline void toggleOutput(int pin) {
	auto port = getPort(pin);
	int pos = pin & 15;
	port->BSRR = (0x00010001 << pos) & ~port->ODR;
}


// peripheral (alternate function)
// -------------------------------

struct PinFunction {
	int pin;
	int function;
};

inline void configureAlternateInput(PinFunction pf, Pull pull = Pull::DISABLED) {
	auto port = getPort(pf.pin);
	int pos2 = (pf.pin & 15) << 1;
	int pos4 = (pf.pin & 7) << 2;

	// set alternate function
	auto &AFR = port->AFR[(pf.pin >> 3) & 1];
	AFR = (AFR & ~(15 << pos4)) | (pf.function << pos4);

	// set pull
	port->PUPDR = (port->PUPDR & ~(3 << pos2)) | (int(pull) << pos2);

	// set mode to alternate function
	port->MODER = (port->MODER & ~(3 << pos2)) | (int(Mode::ALTERNATE) << pos2);
}
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

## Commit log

2021-01-15 Add control, switch and software
    [control.kicad_pcb, control.scad, control.sch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]
2021-01-29 New directory structure and nrf52 os layer
    [control.kicad_pcb, control.sch]
2021-03-15 New emulator drivers for timer, calendar, poti and display
2021-03-15 Drivers for air sensor, display, and new Interface class for local and bus devices
2021-03-15 BME680Test works, Add devices menu entries, several fixes
    [BME680.cpp, LocalInterface.cpp, LocalInterface.hpp]
2021-03-15 Add usb driver
2021-03-27 Add event loop and timer::allocate()
2021-05-19 Filter, send and ack for radio driver
2021-05-30 Radio device can receive and send, separation of sysConfig and appConfig
2022-02-01 New mqtt-sn broker based on coroutines (#3)
    Add new stream concept and terminal
    [BME680.cpp, LocalInterface.cpp, LocalInterface.hpp]
2022-02-16 New input abstraction, renamed/moved sysConfig to boardConfig (#5)
2022-02-18 SPI supports data/command, remove separate display interface (#6)
2022-03-19 Add support for stm32f0 (#9)
2022-04-09 Add switch software (#11)
2022-06-04 Functions (#13)
    * Functions for light, blind and heating
    * New publishing scheme
2022-07-15 New storage (#16)
    New flash key/value storage inspired by Zephyr and ESP32
2022-08-28 Fix USB and radio drivers (#19)
    [boardConfig.hpp, main.cpp]
2022-10-13 Message Listeners (#22)
    * Add display listeners
    * Add control by wheel
2022-10-27 New drivers (#23)
    * SPI, Storage, BusMaster, BusNode, QuadratureDecoder
2022-11-20 First prototype of PCB and switch to KiCad 6 (#25)
    [control.kicad_pcb, control.kicad_sch, control.scad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]
